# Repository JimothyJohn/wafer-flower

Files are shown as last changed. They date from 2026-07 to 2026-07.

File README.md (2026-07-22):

# [Wafer Flower](https://jimothyjohn.github.io/wafer-flower/)

It's the seeds of an idea.

Not a set of programming instructions, but a set of build instructions.

Dimensions clearly understood, relationships alive and interconnected, numbers converted to text to numbers to vectors to topology from your brain onto the 3D printer...it's not a wafer flower, it's not AI slop either, it's not even hard. It's it.

## Really though, what is it?

The current CAD is viewable live at [jimothyjohn.github.io/wafer-flower/viewer.html](https://jimothyjohn.github.io/wafer-flower/viewer.html) — the real exported STLs, with the cure jig opening and closing, the wafer placing, the ring connecting station by station, and the interference checks that gate every one of those configurations in CI.

It's an experiment in how to collaborate iwth AI in both the digital and physical world. Information is contextualized, digested understood, and converted into beautifully-printed reality. Also a ways in I was blown away by how well CAD could be generated, see [stl/](stl/). The entire workholding conceptually made sense and looked like it would actually work...

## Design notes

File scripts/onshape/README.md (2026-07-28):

# OnShape FeatureScript port — Halo beveloid drive

`wafer_halo_beveloid.fs` gives OnShape native, procedural generation of the
gear at the segment edge (straight or spiral), in the style of Anthony Lu's
**Gear Lab** FeatureScript. Paste it into a Feature Studio (New tab →
Feature Studio), commit, and the two features appear in the Part Studio
toolbar under the custom-features flyout.

## The two features

| Feature | What it builds | How to use it |
|---|---|---|
| **Halo Beveloid Band** | One segment's 40° external tooth band: 45° cone big-at-wall, flush root at the band OD, joints mid-space. | Build at origin (wall face on XY, sector centred on +X), then boolean-union onto the segment body. `Full ring` gives all N sectors for assembly checks. |
| **Halo Crossed Pinion** | The Rev B.5 drive pinion: 20T 45° cone (Ø9.9→Ø25.3 tips), apex toward the halo centre, hub + D-bore on the big end. | Mate its axis **radial** — vertical at 12 o'clock, motor above, shaft down — small end at the reported ring radius, axis ~13.6 mm in front of the ring's wall plane. Ratio 5.4:1 → ~2 rpm, PWM-dialed. |

Both features default to the shipped Rev B.3 numbers (N=9, Ri=255, bw=30,
module 5.6 nominal → 5.384 flush, face 9.5, PA 20°, straight teeth). Spiral
is one slider — the sections get the same twist the Python twist-extrude
applies.

## Why not Gear Lab directly?

Gear Lab is excellent for its domain, but its bevel gears are **spherical
involutes for intersecting shafts sized for true rolling** — and a
true-rolling 45°/45° pair only exists at 1:1. The halo pair runs 90° shafts
at 5.4:1 with both members on 45° cones, which no rolling-cone construction
allows; the flanks are conjugate because the Python model **generates**
them under the imposed motion, and the FS features rebuild those envelopes
analytically. The pinion can also be far smaller than the rolling size
(rho is free — that's what keeps the sculpture low-profile). Gear Lab also
has no ring-sector output, no flush-root module retune, and no joint-phase
convention.

Gear Lab is still the right tool if you just want to eyeball a 45° bevel
pair on intersecting axes, or generate a plain spur.

## Fidelity vs the Python model

`scripts/segment_stl.py` **generates** the ring as the swept envelope of
its cutter (conjugate by construction, mesh sweep gated at ≤0.05 mm³). The
FS features build **analytic involute sections and loft** — identical at
the mid-face, a few hundredths off toward the faces. At this drive's
~mN·m loads that is cosmetic; keep backlash ≥ 0.3 mm on printed parts (the
repo ships 0.3 — at the pinion's 0.8 mm section module, 0.6 would halve
the tooth). The Python gates remain the authority for anything that
prints — in particular the **gear_F ceiling** (face height must clear the
neighbour wafer's clearance plane; the gate computes 9.83 mm at the deep-bevel base (tmin=15)).

## Crib sheet at Rev B.5 (low-profile)

- 108T ring (12/segment), flush module **5.384** (5.6 nominal)
- Front radii: root 284.0, pitch 290.7, tip 296.1; wall = front × 1.0327
- Face 9.5 mm, cone 45°, straight (spiral 0°)
- 20T crossed pinion: pitch rho 8 (FREE — not the rolling value; conjugacy
  is by generation; 8 at 20T = the 0.8 mm section-module print floor),
  face 7, tips Ø9.9→Ø25.3, axis 13.6 mm off the wall plane
- Ratio 108/20 = **5.4:1** — ~2 rpm at the ring from an ~11 rpm shaft
  (22PG-2430BL 720:1, integrated driver, PWM-dialed; catalog-typical
  ~16 rpm no-load → ~3 rpm ceiling)
- Hub Ø16 × 6 mm on the big (motor) end, bore Ø4.2 with 0.5 D-flat
  (22PG 4 mm D-shaft — catalog-typical, measure the purchased unit)

`docs/onshape-variables.html` still carries the 46 copy-paste variable
expressions for the rest of the segment; these features replace only the
gear, which was the one part DXF import couldn't make parametric.

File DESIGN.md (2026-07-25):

# Design Guide

This is a high-level design guide that will aid with the creation of an optimal sectional mounting frame based on specific design criteria.

## Fabrication

This will be manufactured on a Bambu H2S printer.

## Concepts

### Symmetry

All components should be idnetical and designed in such a way that they easily assemble together without tools. There will be an assembly jig that attaches to each frame component, and the sculpture will be mounted by taking advantage of the same jig mounting features to attach it to the wall.

### Footprint

The frame should be as low profile as possible while still limiting interference from 300mm wafers neighbored, mounted, and tilted towards its adjacent components.

### Drivetrain

Each segment will incorporate a spiral bevel rack on the inner (outer is possible in the future) radius that will engage a pinion to rotate the entire frame at a constant velocity.

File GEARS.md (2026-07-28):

# GEARS.md — why these bevel gears work, and how to generate yours

This is the clinic. It explains why the Wafer Halo's gear train — a 108-tooth
45° bevel rack on the sculpture's OD, driven at 5.4:1 by a 20-tooth conical
pinion on a vertical shaft — meshes correctly *as generated*, why classical
bevel-gear theory said it couldn't exist, and exactly which constraints are
load-bearing versus free, so the same method can be re-targeted
algorithmically (different ring size, ratio, motor, cone angle) without
re-deriving anything by hand. Every claim cites the code that enforces it;
all excerpts are from `scripts/segment_stl.py` unless noted.

The one-sentence version: **don't specify tooth flanks — carve them, by
sweeping the actual mating part through the exact relative motion, and let
boolean gates prove the result.**

---

## 1. The problem that theory can't solve

The drive wants four things simultaneously:

1. A **45° straight bevel rack** on the ring's outside diameter — the mixer
   look, working face toward the viewer (aesthetic, non-negotiable).
2. A **~2 rpm target** at the sculpture, minimalist over exact. The 5.4:1
   ratio (20T pinion) puts any small gearmotor in range: the 22PG-2430BL
   720:1 (integrated driver, catalog-typical ~16 rpm no-load) lands ~3 rpm
   and PWMs down to taste; the earlier Pololu #1596 at 5 V (10.83 rpm
   no-load) would give 2.006 rpm on the same teeth.
3. The pinion shaft **pointing straight down** (radial at 12 o'clock), motor
   directly above it.
4. Packaging: silicon wafers own *all* space in front of the ring (their
   undersides sweep within millimetres of the tooth band), and drywall owns
   the space behind.

Classical bevel gearing cannot deliver this. Two true-rolling bevel gears
must share a pitch-cone **apex** on the line where their shafts intersect,
and the cone angles are then *dictated* by the ratio:
`tan δ₂ = sin Σ / (ratio + cos Σ)`. Consequences, all measured in this repo
before being abandoned:

- A **45°/45° pair only rolls at 1:1**. At 5.4:1 with 90° shafts the ring
  cone must be ~79.5° (nearly a flat face gear) and the pinion ~10.5° (nearly
  a spur) — no mixer look.
- Keeping the ring at 45° and solving for true rolling puts the shared apex
  **~300 mm in front of the wall** on the halo axis; the pinion and motor
  would hang in the wafer field.
- The interim parallel-axis beveloid solved packaging but put the shaft
  along the wall normal — not the drive Nick specified.
- A rolling-sized radial-axis pinion (pitch = ring pitch ÷ ratio = 26.9 mm)
  ballooned to Ø100 at the big end and forced a 108 mm-tall part before the
  size assumption was questioned (§4).

## 2. The move: generation, not specification

The escape is the same one machine tools use. A hobbed or shaped gear is
never *drawn* — the cutter and blank are driven through the meshing motion
and the flanks emerge as the envelope of material that survives. Conjugacy
is then true **by construction**: the running pinion cannot interfere with
flanks its own shape cut while executing the exact motion it will run.

Here that principle is executed volumetrically with CSG (`manifold3d`): the
cutter is a solid model of the pinion, placed at ~500 successive poses of
the relative motion, unioned, and subtracted from the ring blank. The core
of `gear_teeth_bevel45()`:

```python
# segment_stl.py, gear_teeth_bevel45() — the generation sweep.
# One pose per step: the pinion spun ratio*d about its own axis, placed on
# the radial axis, then the whole pose rotated -d so the ring stays still.
cutter_pin, _ = bevel_pinion(cf, backlash=0.0, over=0.5)
n = steps or (48 * int(round(cf.gear_m)) + 1)
span = span_pitches * (2.0 * math.pi / cf.teeth)      # ±2 ring pitches
cut = union_all([(bevel_pinion_at(cf, cutter_pin,
                                  -span / 2.0 + span * i / (n - 1), dr=-0.3)
                  .rotate([0, 0, -math.degrees(-span / 2.0
                                               + span * i / (n - 1))]))
                 for i in range(n)])
gen = blank - cut
```

and the pose function that encodes the crossed-axis kinematics:

```python
# segment_stl.py, bevel_pinion_at() — the imposed motion.
def bevel_pinion_at(cf, pin, d, dr=0.0):
    bg = bevel_geom(cf)
    return (pin.rotate([0.0, 0.0, math.degrees(d * bg['ratio'])])
               .rotate([0.0, 90.0, 0.0])
               .translate([bg['x0'], 0.0, bg['zax'] + dr]))
```

Read it kinematically: while the ring turns `d`, the pinion turns
`ratio · d` about its own (radial) axis. `rotate([0,90,0])` maps the
pinion's local +z (its axis) onto the global radial direction, which also
lands its phase-0 tooth pointing down into the ring. The `.rotate(-d)` in
the sweep transfers the ring's share of the motion onto the cutter, so the
blank can stay fixed. That pair of lines *is* the gear theory in this repo.
The spin sign was derived once by matching surface velocities at the
contact and is *verified*, not trusted — a wrong sign reads as hundreds of
mm³ in the mesh gate (§6).

Because the flanks are an envelope of an imposed motion rather than rolling
involutes, this pair runs with sliding contact, like a cam or a worm. At
this drive's loads (~3 mN·m needed against a 0.54 N·m stall through the
gearbox) sliding is irrelevant; the printed PLA pinion doubles as the
mechanical fuse.

## 3. The two constraints that are actually load-bearing

Everything about this drive is negotiable except two integers.

**Ring tooth count must divide by N.** The ring is assembled from N=9
identical printed segments; if the tooth pattern doesn't tile the 40° joint
exactly, the pitch breaks at every seam. So `teeth = tps × N`, and the
pattern is phased so **every joint lands mid-space** (a space at azimuth 0,
copies at `k·pitch` — see §5d).

**Ratio = ring teeth ÷ pinion teeth, exactly.** Tooth-passing frequency
must match at the mesh, so `108 / pin_T = ratio`. Wanting ~2 rpm forces
`pin_T = 20` (5.4:1). This is the *only* thing the RPM goal fixes:

```python
# segment_stl.py PARAMS
pin_T    = 20,      # pinion tooth count. 108T ring / 20T = 5.4:1 —
                    # the Pololu #1596 at 5 V (10.83 no-load rpm) gives
                    # 2.01 rpm at the ring (2026-07-27, Nick: ~2 rpm is
                    # fine, minimalist profile beats exact-1; pin_T 10
                    # was the 1.00 rpm build). NOTE finer RACK teeth
                    # would RAISE the profile: more ring teeth needs
                    # more pinion teeth per ratio, and the pinion's
                    # printability floor is its section module
                    # (2*pin_rho/pin_T >= ~0.8).
```

One subtlety worth internalizing: pinion tooth count and pinion *size* are
coupled through printability, not kinematics. A 20T pinion at rho 8 has a
0.8 mm section module — the FDM floor — so doubling the tooth count again
(1 rpm-class ratios with finer rack teeth) would force a *bigger* pinion
and a *taller* part. Coarse rack + few-but-chunky pinion teeth is the
low-profile direction.

Note what is *not* on this list: the pinion's size, and even its cone
angle. That's the subject of the next section, and it's the difference
between the Ø100 monster and the Ø25 pinion that shipped.

## 4. The freedom theorem: pinion size is a style knob

Textbook reflex says the pinion's pitch radius must be
`ring_pitch / ratio` (rolling contact at the pitch point). The first
crossed-axis build obeyed that reflex — rho 26.9 mm, tips Ø100, the motor
36 mm off the wall, the whole part 108 mm tall — and got the correct
review: *"way out of scale… it should be right up on its nuts."*

The reflex is wrong **because generation owns conjugacy**. The sweep makes
the ring conjugate to whatever cutter executes the motion; rolling is a
contact-quality optimization, not a meshing requirement. Only the tooth
count is forced. So the pinion's pitch radius and engaged face are free
parameters, sized for packaging:

```python
# segment_stl.py PARAMS
pin_rho  = 8.0,     # pinion mid-face pitch radius. FREE, not the
                    # rolling value (conjugacy is by generation; only
                    # the COUNT is forced). 8 with pin_T 20 = 0.8 mm
                    # section module — the printable floor, and the
                    # low-profile knob: the standoff is ~2.25*rho +
                    # gear_F/2 + face/2 dominated.
pin_face = 7.0,     # pinion face length along its axis: engages the
                    # OUTER pin_face mm of the tooth radial envelope.
```

With rho = 8 the pinion is a Ø9.9→Ø25.3 cone, its axis 13.6 mm off the
wall face, and the derived wafer standoff collapses to +17.6 mm (§7) —
the rolling-size first cut was +78, the rho-12 rev +31. The floor is the
0.8 mm section module (`2·pin_rho/pin_T`): below that FDM teeth stop
resolving. The cost of abandoning rolling is extra sliding — already
accepted at these mN·m loads.

## 5. The recipe

### a. Size the ring teeth: flush module by retune

Tooth count is quantized in steps of N, so the pitch radius can't be tuned
by count. Instead the *module* is retuned so the root circle lands on the
band's outer wall — teeth rise straight off the part, no bare web:

```python
# segment_stl.py, Cfg — FLUSH MODULE
target = self.Ro + 1.25 * self.gear_m + 2.0
self.tps = max(6, int(math.ceil(2 * target / self.gear_m / self.N)))
self.teeth   = self.tps * self.N
if self.g_bev:
    self.gear_m = (self.Ro - 1.0) / (self.teeth / 2.0 - 1.25)
```

At the shipped numbers: nominal module 5.6 → 12 teeth/segment → 108 teeth →
effective module 5.384, root at r284 against the band OD at 285.

### b. The ring blank owns the look

The visible 45° cone is *not* produced by the cutter — it's the blank: an
annulus intersected with a cone, big end at the wall (radius falls 1 mm per
mm of z toward the viewer):

```python
# segment_stl.py, gear_teeth_bevel45() — the blank
big = cf.g_tip * cf.g_kbig + 1.0
blank = prism(arc(big, -cf.half, cf.half, 200) +
              arc(cf.g_web_i, cf.half, -cf.half, 200), 0.0, F)
tipcone = (Manifold.cylinder(F + 0.2, cf.g_tip * cf.g_kbig + 0.1,
                             cf.g_tip + 0.1, 512)
           .translate([0.0, 0.0, -0.1]))
blank = blank ^ tipcone
```

This separation matters for generality: change the blank and the gear's
silhouette changes; the cutter sweep only decides where the working flanks
are. The face height `gear_F` has a *live-computed* ceiling — the band must
clear the neighbouring wafer's clearance plane, measured by
`gear_F_ceiling()` and enforced by a gate in `main()` that fails the build
if the mandatory clearance cut removes any tooth material.

### c. Build the cutter: a cone of scaled involutes

The cutter (and the printed runner) is the pinion: standard external
involute sections, scaled linearly along the axis so the envelope is a 45°
cone. Linear scaling with `scale_top` gives exactly 1 mm of radius per mm
of length:

```python
# segment_stl.py, bevel_pinion() — sections scaled (station − apex)/rp0
s_lo = (bg['x0'] - over - bg['apex']) / rp0
s_hi = (bg['x1'] + over - bg['apex']) / rp0
p = Manifold.extrude(CrossSection([pts]), bg['face'] + 2 * over,
                     n_divisions=16, twist_degrees=tw,
                     scale_top=(s_hi / s_lo,) * 2)
```

Two details are traps, both encoded: `over=0.5` extends the cutter past
both faces (a cutter ending exactly on a face leaves sliver faces that read
as OPEN after the float32 STL weld), and `twist_degrees` is where a spiral
would go — set `gear_sp`, and the *generated ring inherits the conjugate
spiral automatically*, because the sweep doesn't care what the cutter looks
like.

### d. Sweep, extract, pattern, clip

The sweep spans ±2 ring pitches (`span_pitches=4`) — enough for the cutter
to fully enter and leave a space, which is also what proves tooth handoff.
Then one pitch is extracted and patterned, because the motion is periodic:

```python
# segment_stl.py, gear_teeth_bevel45() — pattern and clip
one = gen ^ wedge                       # one-pitch sample, cut at angle 0
teeth = union_all([one.rotate([0.0, 0.0, -math.degrees(cf.half) + k * pitch])
                   for k in range(cf.tps + 1)])
eps = 1e-5
sector = prism([(0.0, 0.0)] + arc(big + 100.0, -cf.half + eps,
                                  cf.half - eps, 64), -1.0, F + 2.0)
teeth = teeth ^ sector
```

Three phase/pattern rules, each learned the hard way (measured values in
CLAUDE.md): the cutter cuts a **space at angle 0**, so copies tile at
`k·pitch` from the joint (a half-pitch offset reads as ~156 mm³ of joint
interference); **tps+1 copies** are generated then clipped (an unclipped
end wedge lands 232 mm³ inside the neighbour segment); and the sector clip
backs off **1e-5 rad** from the exact joint plane (numerically coincident
faces on assembled neighbours read as phantom interference).

Tip relief is **radial** — the cutter runs with `dr = -0.3`, i.e. its whole
axis 0.3 mm closer to the ring than the runner will sit, so slot floors are
uniformly deeper than running tips. The obvious alternative (shifting the
cutter along z) was shipped once and left a visible uncut 0.3 mm shelf ring
at the wall-face edge of every tooth.

### e. The cosmetic pass: look and function, decoupled

The small pinion only needs the outer 10 mm of the tooth envelope, but the
*visible* pattern should span the whole 45° face. So a second sweep runs a
full-face parallel-axis beveloid cutter over the blank, purely for
appearance. This is safe by a monotonicity argument worth internalizing:
**extra material removal can only add clearance** — it cannot create
interference — so the mesh gate is untouched. Both patterns tile at
`k·pitch`, so they align tooth-for-tooth:

```python
# segment_stl.py, gear_teeth_bevel45() — cosmetic pass (excerpt)
# ... the small crossed pinion only carves the outer pin_face of the
# envelope; the visible deep-bevel tooth pattern is restored by ALSO
# sweeping the old parallel-axis 12T beveloid cutter over the full face.
cut = cut + union_all([
    (cos_pin.rotate([0.0, 0.0, -math.degrees(d * cf.teeth / cf.tps)])
            .translate([C - 0.3, 0.0, 0.0])
            .rotate([0, 0, -math.degrees(d)]))
    for d in (-span / 2.0 + span * i / (nc - 1) for i in range(nc))])
```

### f. Cutter vs runner: backlash by thinning

The generating cutter runs at zero backlash; the printed runner is the same
solid with teeth thinned by `gear_bl = 0.6` mm (`pinion_profile`'s
`psi_p` term). Running clearance therefore exists **by construction**:
flank clearance from the thinning, tip clearance from the radial relief.
0.6 mm is the printed-PLA tune; it is a parameter, not a constant.

## 6. Why meshing is guaranteed — the gates

Generation makes interference impossible *up to discretization* (the sweep
is a union of poses, so the true envelope is scalloped at the step
spacing). The residual is measured, not assumed:

```python
# segment_stl.py, check_mesh() — roll the RUNNER against the generated
# teeth through one full ring pitch and measure boolean overlap
for i in range(steps):
    d = (2 * math.pi / cf.teeth) * i / steps
    r2 = ring.rotate([0, 0, math.degrees(d)])
    p2 = bevel_pinion_at(cf, pin, d)
    worst = max(worst, (r2 ^ p2).volume())
```

CI fails the build if `worst > 0.05 mm³`; the shipped geometry measures
**0.00000 mm³**. The same number is the arbiter for the motion's spin sign
and phase — a wrong sign or a half-pitch phase error reads as hundreds of
mm³, so the convention can never silently rot.

The rest of the gate suite closes the environment: the neighbour-wafer
clearance cut must remove zero tooth material (its ceiling on `gear_F` is
computed live from the wafer geometry, not frozen in a comment); assembled
neighbour segments must measure exactly 0 interference; every body must be
watertight with the expected genus, with sub-0.01 mm³ specks filtered at
the source because a disconnected crumb cancels a handle in the Euler count
and masquerades as correct topology. Downstream, `bracket_stl.py` checks
the *running context*: the pinion against the full ring + wafer field at
nominal, the wall plane including the pinion's swing, and the wheel datum
that preloads the mesh.

## 7. Packaging closes the loop

Two derived quantities tie the gear to the sculpture, both computed in
`Cfg`, neither hand-maintained:

- **`stand`** — the wafers must clear the pinion's front bulge, so the part
  grows exactly as much as the drive needs:
  `pin_bulge = pin_zax + (pin_x1 − pin_apex)·(1 + 2/pin_T)`, and
  `stand = pin_bulge + 3 − gap₀`. At rho 8 that's +17.6 mm (+31 at rho 12,
  +78 at the rolling-sized pinion — shrinking the pinion shrinks the
  sculpture, until the 0.8 mm section-module print floor stops it).
- **wall gap** — the pinion's lower teeth swing `(x1−apex)·(1+2/pin_T) −
  zax` past the ring's wall face (at shipped numbers that's −0.9 mm: the
  small pinion never crosses the wall plane); the mount holds the ring
  6 mm off the drywall and the wall-plane check proves it either way.

The mount side completes the mesh mechanics: the two bore idlers hang the
ring **at the meshing meridian**, so the pinion presses against a hard
radial datum, and the motor shell rides ±8 mm slots to set engagement depth
(preload) before clamping.

## 8. Re-targeting checklist (the algorithm, as an algorithm)

To generate a different bevel drive with this machinery:

1. Pick ring size (`Ri`, `bw`) and nominal module for tooth chunkiness;
   the flush retune (§5a) makes the count/size self-consistent.
2. Pick the ratio from your speed goal; `pin_T = teeth / ratio` must land
   on an integer — that's the only place the RPM constrains the geometry.
3. Pick `pin_rho` and `pin_face` for packaging (motor location, bulge,
   behind-face swing). These are free (§4).
4. Pick the blank's cone (`gear_F`, big end direction) for looks, under
   the live environmental ceiling.
5. Optional spiral: one parameter (`gear_sp`); the ring inherits it.
6. Run the generator. The sweep produces the conjugate flanks; the gates
   (mesh sweep, clearance cut, pair fit, watertightness, context checks)
   either prove the result or point at exactly which assumption broke.

Nothing in the list involves drawing a tooth.

---

*Related: `scripts/onshape/wafer_halo_beveloid.fs` reproduces the ring
band and pinion analytically for OnShape CAD work (parity-tested spec
math); the generated Python parts remain the authority for anything that
prints. History and the full trap ledger live in `CLAUDE.md`.*

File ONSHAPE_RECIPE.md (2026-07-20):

# Build v3 in OnShape from the DXFs — 7 features

Import both DXFs as sketches on the Top plane (they share the same global
coordinate system; segment is centered on +X).

## The one construction that matters: the LAND PLANE
1. Sketch a line on Top along the TILT_AXIS layer (through wafer center
   (350,0), pointing radially).
2. Plane > Line Angle: through that line, 20 deg from Top. This is the
   WAFER MID-PLANE.
3. Offset plane: -0.887 mm below it (wafer half-thickness 0.3875 + 0.5
   bond line). This is the LAND PLANE.

## Segment (one part, pattern is implicit — print 9)
1. Extrude SECTOR profile DOWN 8 mm (base).
2. Extrude LAND_FOOTPRINT profile UP 40 mm, merge with base.
3. Split/Remove everything above the LAND PLANE (Boolean with a large
   extruded region, or Surface > Plane + Split part, delete upper body).
   The surviving ramped top face is the bonding land.
4. Dovetails: on the +20 deg radial end face sketch DT_MALE, extrude 8 out;
   on the -20 deg face sketch DT_FEMALE, extrude cut through.
5. Nubs: sketch 3x d4 circles ON THE LAND PLANE at (220,0), (235,±32.89)
   [plan coords — use the NUBS_D4 layer as reference], extrude UP 0.5 mm.
6. Keyhole: cut 3 deep into the bottom face from the KEYHOLE layer.

## Jig
1. Extrude RAIL_IN and RAIL_OUT down/up per notes (rails 13 tall total,
   dropping 8 below Top to straddle the segment base).
2. Registration dovetail: reuse DT_MALE minus ~0.05 on the -20 deg end.
3. Fences: extrude FENCE_* profiles from the LAND PLANE up ~5.5 mm
   (use Up to Next/offset from the tilted plane, not from Top — the fence
   top must parallel the wafer, not the bench).
4. Bridge: extrude BRIDGE_FOOTPRINT as a bar spanning the rails ~30 above
   Top; cut the M5 hole NORMAL TO THE WAFER MID-PLANE at plan (228, 0);
   hex nut pocket 8.1 AF x 4.2 on top.

## Numbers you'll want while modeling
- Wafer: d300 x 0.775. Halo: N9, pitch R350, tilt 20 about radial axis.
- Sector: 40 deg, Ri 175 / Ro 245, base 8. Dovetail 12/16 x 8, clr 0.25.
- Land margin inside wafer edge: 3. Bond line: 0.5 (nubs d4 x 0.5).
- Fence inner face at R150.3 from wafer center; walls 5 thick.
- Bond adhesive: MS-polymer (SikaFlex 252 / Loctite PL), not rigid epoxy.

## Sanity checks after modeling
- Section through the wafer mid-plane: wafer back should sit 0.5 above the
  land everywhere, kissing the three nubs.
- Assembly with 9 instances @ 40 deg: neighbor wafer clears this segment's
  land everywhere (it does at 20 deg tilt by ~50 mm; verify if you change
  tilt, R_pitch, or ring widths).
- Land must stay inside the wafer outline in front view (3 mm margin).

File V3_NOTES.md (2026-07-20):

# Halo v3 — adhesive mount, zero frame hardware

## What's on the frame (per segment, x9)
Dovetails, three 0.5 mm bond-line nubs, an underside keyhole. Nothing else.
The bonding land is generated by cutting the segment blank with the
wafer-back plane, so it is coplanar with the wafer underside by construction
and covers every point where the wafer footprint overlaps the frame
(~110 x 40 mm lens through the segment middle at default params).
Want more land? Widen body_ri/body_ro — do NOT expect land at the segment
ends; the wafer has curved away there.

## Bonding procedure (bench, one segment at a time)
1. Print jig once. Fit-check jig on a bare segment: dovetail seats, rails
   straddle the base with no rock.
2. Dry-run: wafer onto the land, slide until edge rests on the downhill
   fence, finger-press toward the 180° fence pad until it touches both.
   That's centered. Practice this before adhesive.
3. Mask nothing; apply MS-polymer (SikaFlex 252 / Loctite PL) in a
   serpentine bead over the land, staying ~5 mm inside its edge.
4. Place wafer, center against fences as rehearsed, install clamp knob,
   turn until the pad JUST contacts, then 1/4 turn. The nubs stop it —
   you are setting bond line, not applying force.
5. Cure per datasheet (MS polymers: handle 24 h, full 72 h). Remove jig,
   next segment.
6. After all nine: dovetail the ring together, hang on 3 keyholes.

## Adhesive
MS-polymer or E6000, not rigid epoxy: PLA/PETG vs silicon CTE mismatch over
a 110 mm bond puts thermal shear into the wafer. If you insist on epoxy,
use a flexibilized one (3M DP125) and keep the 0.5 mm bond line.

## Known v1 risks — check on first render/print
1. UNRENDERED (no OpenSCAD in my environment). projection() of the tilted
   cylinder is the one construct most likely to be slow or need a render
   (F6) instead of preview; if it drags, replace wafer_footprint_prism()
   with a linear_extrude of an approximated ellipse (semi-axes 150 radial,
   150*cos(tilt) tangential, centered at R_pitch).
2. Jig fence struts and bridge are placed by hand-calculated offsets —
   expect to nudge them after first F5. Printables (segment, jig) before
   scene modes.
3. The downhill fence assumes bonding with the segment flat on the bench
   (wafer plane tilted 20 deg, low side = local -Y/270 deg). If you bond in
   any other orientation, move the fence to whatever side is downhill.
4. Land surface is a plane cut across layer lines — print segments land-up
   with fine layers, or hit the land with one pass of filler/sand for full
   adhesive contact. Nubs survive light sanding; don't flatten them.

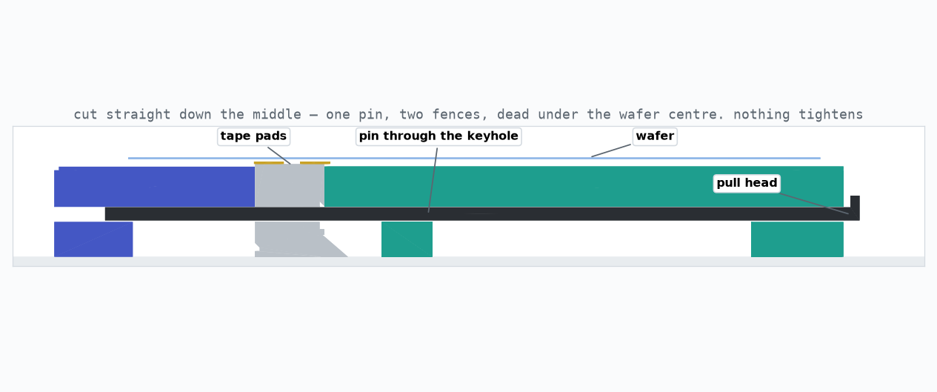
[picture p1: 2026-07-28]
docs/media/sec_drivetrain.png

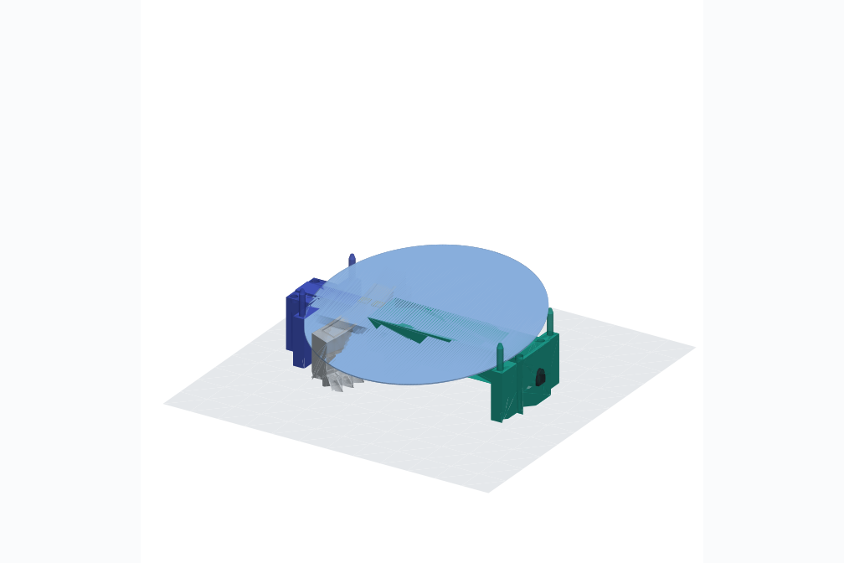
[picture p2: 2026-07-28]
docs/media/hero.png

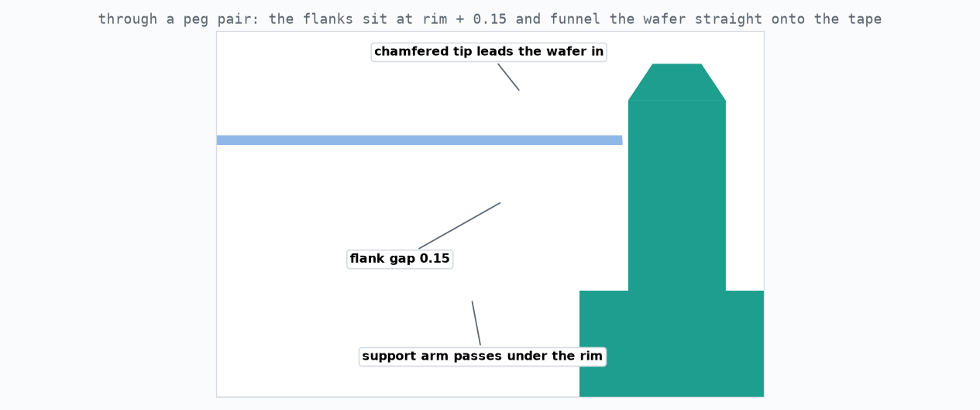
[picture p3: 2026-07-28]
docs/media/sec_capture.png

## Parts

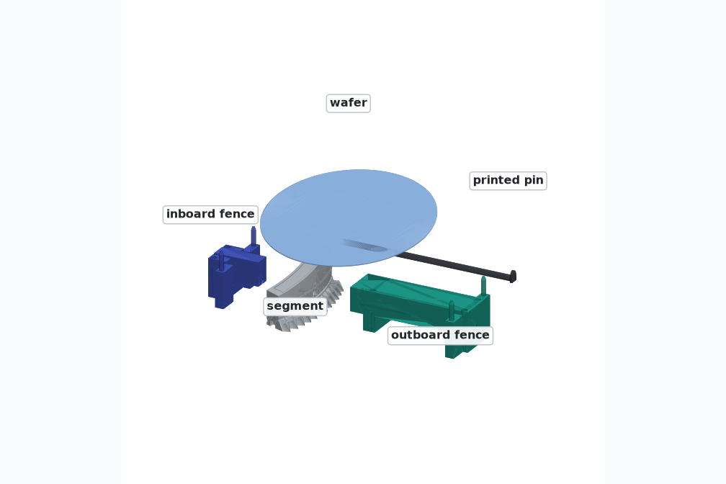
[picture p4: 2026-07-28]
docs/media/parts.png

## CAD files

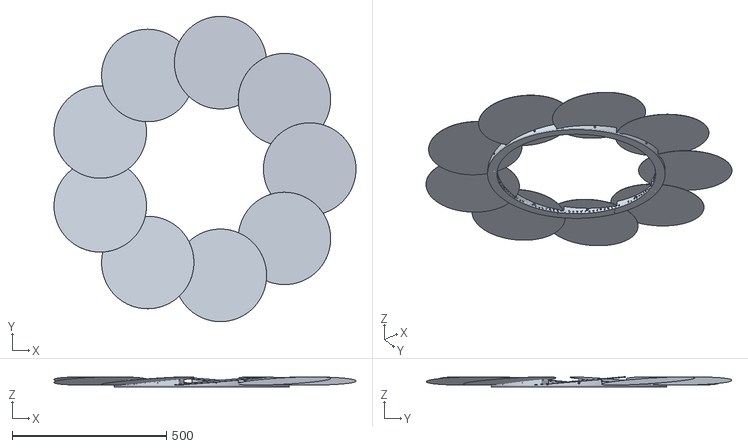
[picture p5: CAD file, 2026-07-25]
stl/halo_assembly.stl
978.8 x 989.3 x 33.5

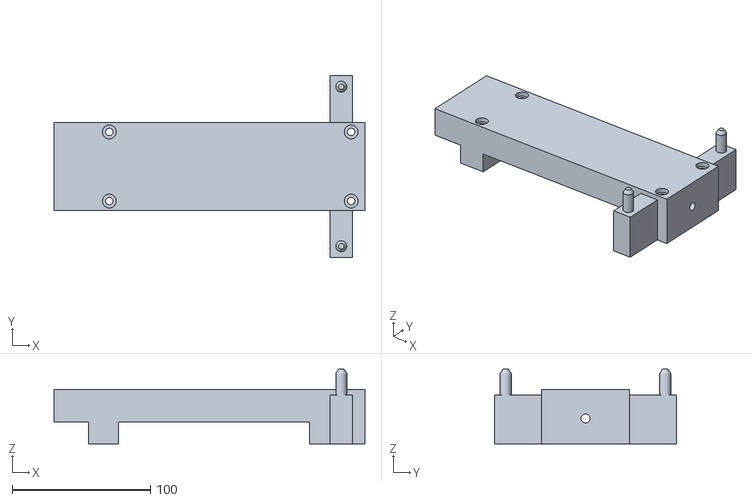
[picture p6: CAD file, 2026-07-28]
docs/models/jig_outboard.stl
225.0 x 131.4 x 54.0

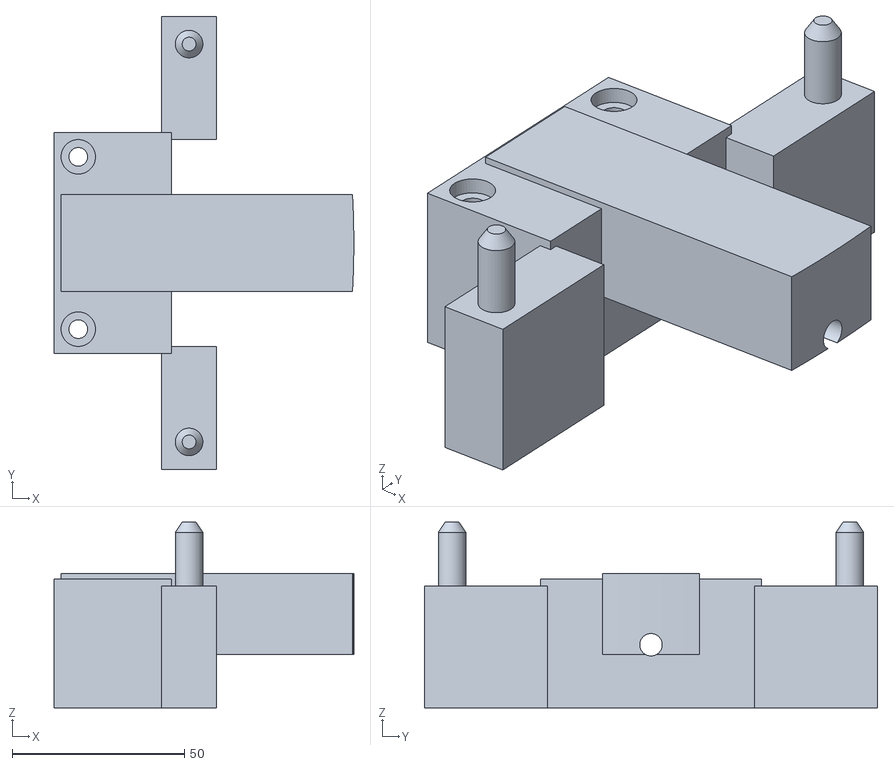
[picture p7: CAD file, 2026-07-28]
stl/cure_jig_inboard.stl
86.9 x 131.4 x 54.0

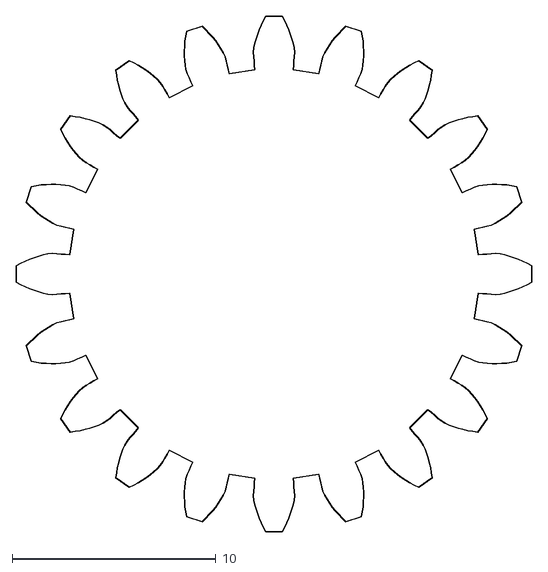
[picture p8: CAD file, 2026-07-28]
stl/dxf/05_bevel_cutter.dxf
25.3 x 25.3

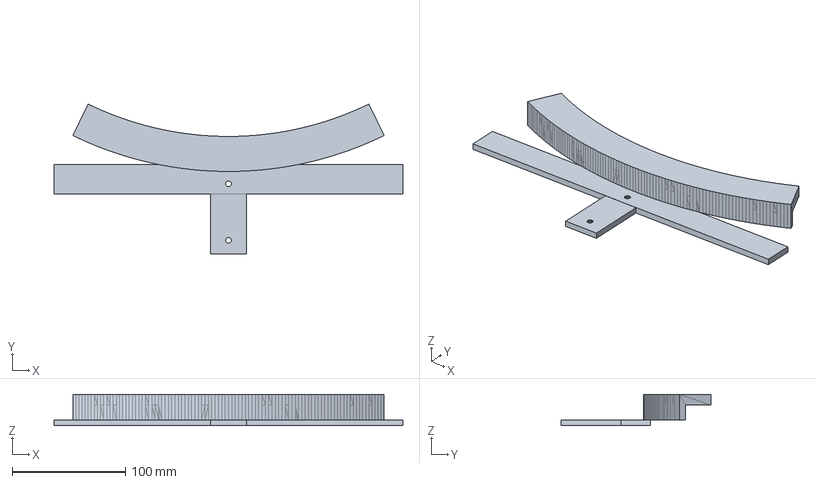
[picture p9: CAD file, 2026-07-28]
stl/step/bracket_static.stp
308.6 x 132.6 x 27.8 mm

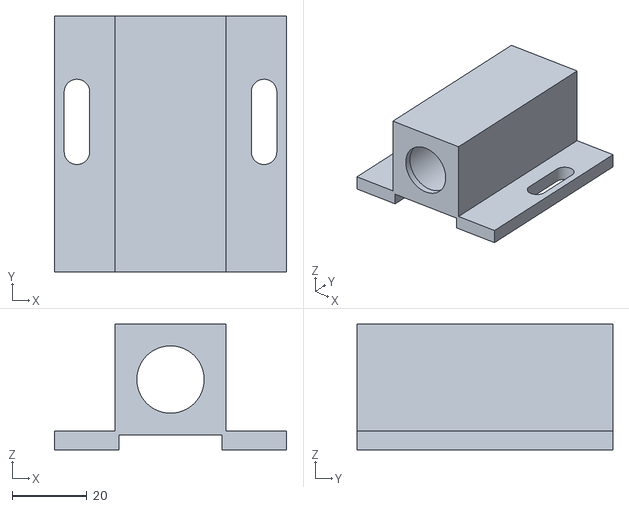
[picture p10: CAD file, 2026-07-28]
docs/models/bracket_shell.stl
62.0 x 68.4 x 33.6

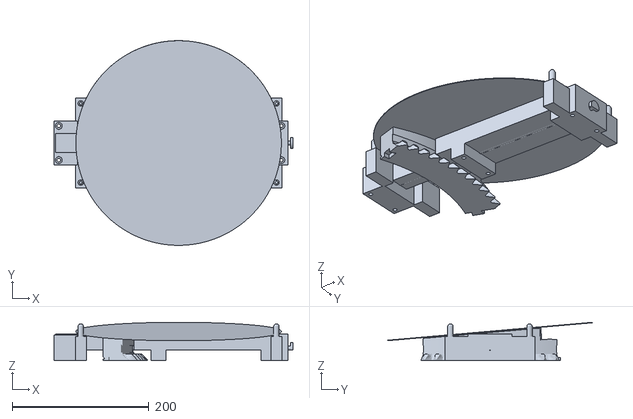
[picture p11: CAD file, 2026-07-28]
stl/cure_jig_fitcheck.stl
349.0 x 298.9 x 56.1

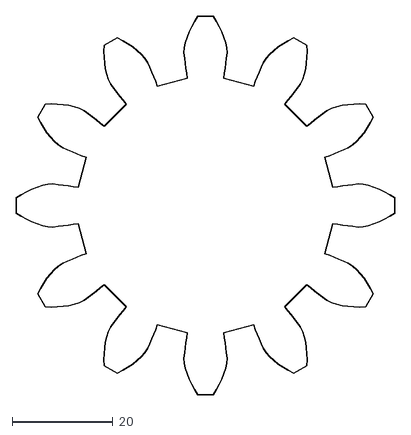
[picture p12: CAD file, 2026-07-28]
stl/dxf/06_pinion.dxf
75.3 x 75.3

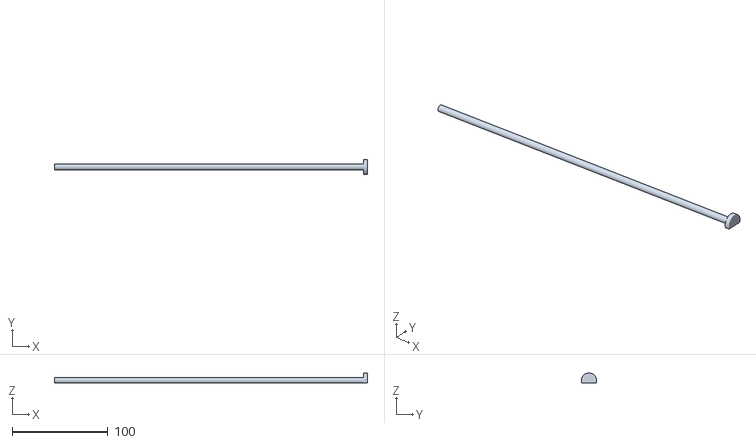
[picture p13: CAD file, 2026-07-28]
docs/models/rod.stl
327.0 x 16.0 x 10.6

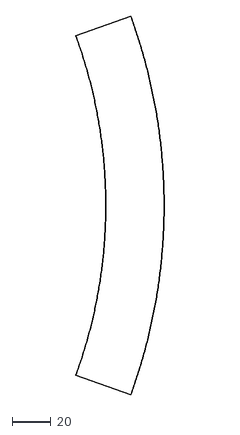
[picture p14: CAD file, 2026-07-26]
stl/dxf/01_band.dxf
45.4 x 194.9

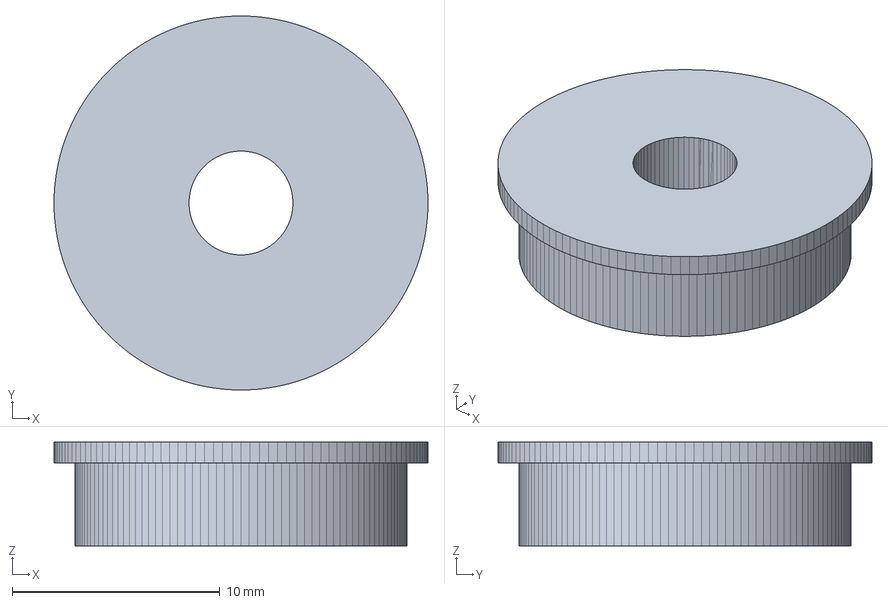
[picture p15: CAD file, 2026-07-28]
stl/step/bracket_wheel.stp
18.0 x 18.0 x 5.00 mm

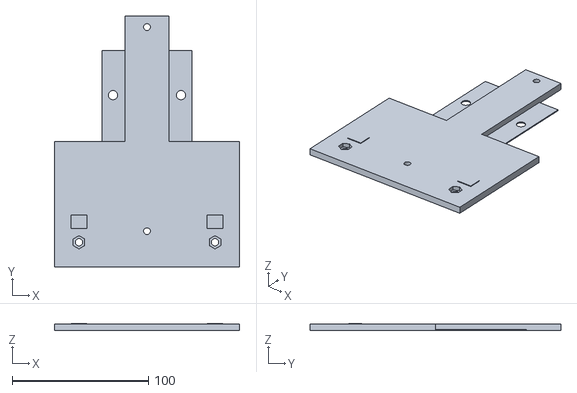
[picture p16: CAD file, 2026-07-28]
docs/models/bracket_top.stl
136.0 x 184.2 x 5.50

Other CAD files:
stl/step/bracket_shell.stp
stl/cure_jig_outboard.stl
stl/bracket_bottom_static.stl
stl/step/bracket_top.stp
docs/models/wheel_r.stl
docs/models/bracket_bottom.stl
docs/models/bracket_plate.stl
docs/models/bracket_static.stl
docs/models/drive_pinion.stl
docs/models/jig_inboard.stl
docs/models/my_frame_segment.stl
docs/models/segment.stl
docs/models/wafer.stl
docs/models/wheel_l.stl
stl/bracket_bottom.stl
stl/bracket_fitcheck.stl
stl/bracket_plate.stl
stl/bracket_shell.stl
stl/bracket_top.stl
stl/cure_jig_pin.stl
stl/drive_clamp.stl
stl/drive_fitcheck.stl
stl/drive_pinion.stl
stl/drive_plate.stl
stl/dxf/02b_tail.dxf
stl/dxf/03_socket.dxf
stl/dxf/04_pocket.dxf
stl/halo_frame.stl
stl/m5_nut.stl
stl/m5_screw.stl
stl/m6_nut.stl
stl/m6_screw.stl
stl/pinion.stl
stl/segment.stl
stl/segment_pair.stl
stl/step/bracket_bottom.stp
stl/step/bracket_plate.stp
stl/step/pinion.stp
stl/step/segment.stp
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

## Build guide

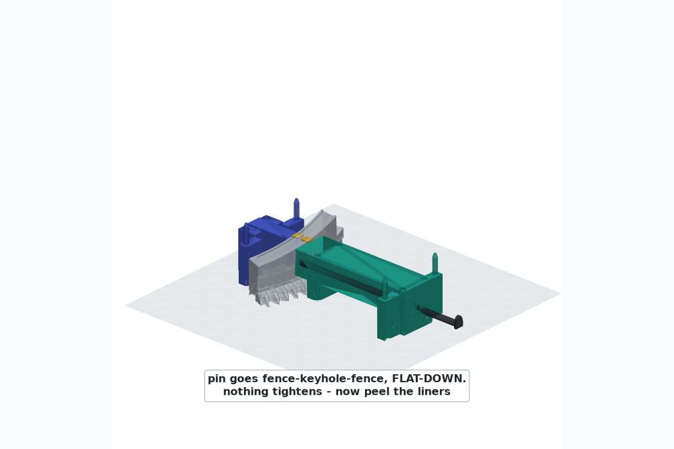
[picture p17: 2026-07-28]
docs/media/step5_pin.png

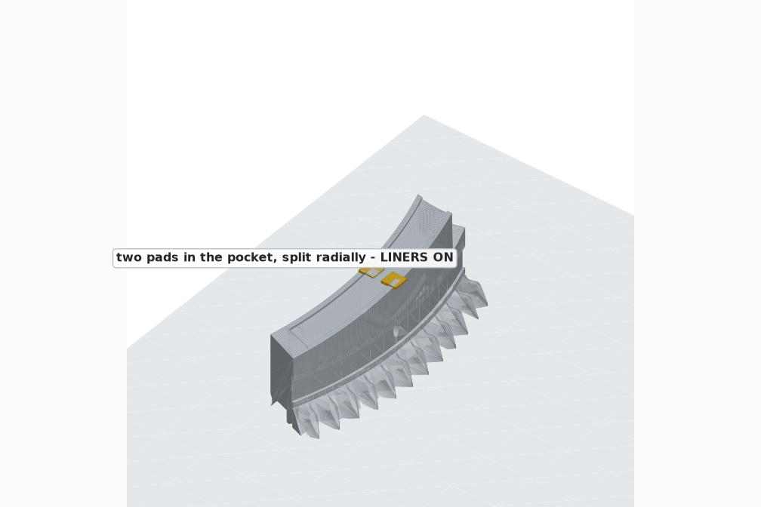
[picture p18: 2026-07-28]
docs/media/step2_tape.png

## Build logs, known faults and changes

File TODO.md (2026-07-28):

# TODO

## Open questions for Nick

(my_frame_segment.stl orientation answered 2026-07-21: same frame as
segment.stl; the viewer overlay expects that and warns until the re-export
lands)

- 2026-07-22 gearmotor: the drive plate's N20-worm envelope (46×12.6×10.2,
  Ø3 D-shaft, shaft 9 mm from the nose end) is catalog-typical, not measured.
  Which unit are you buying? Re-run scripts/gearmotor_stl.py with measured
  dims before printing drive_plate.stl.
- 2026-07-22 bracket interface: the plate hangs on TWO #10-24 pan heads,
  56 mm apart (y=±28), heads ~4 mm proud, in the plane 16.5 mm behind the
  frame's flat bottom (z=−36.5 scene). OK to freeze this as the bracket
  contract, or do you want a different fastener/spacing?
- 2026-07-22 viewer: add the drive module (plate/clamp/motor/pinion) to
  viewer_export.py + docs/viewer.html as a preset? Left out to keep the PR
  additive; the fitcheck STL covers it meanwhile.
(2026-07-26 drive-axis fork answered same day: crossed radial shaft
shipped as Rev B.5 — generation owns conjugacy, the small pinion clears
the wafer field from the front.)

- 2026-07-27 22PG-2430BL 720:1 envelope: bracket_stl.py carries
  CATALOG-TYPICAL dims (body Ø24, nose Ø22×20, length 65, Ø4 D-shaft —
  the RobotShop datasheet PDF is CDN-blocked from here; speed ~16 rpm
  no-load is interpolated from the 19:1/630 rpm and 1370:1/8 rpm
  siblings). Measure the purchased unit (body Ø + length, nose Ø +
  length, shaft Ø + flat, mount holes) and re-run bracket_stl.py before
  printing the shell. Also: it's a 24 V-class motor with an integrated
  driver — what's the supply plan (24 V brick + PWM pot, or a
  microcontroller)? USB 5 V won't run it.

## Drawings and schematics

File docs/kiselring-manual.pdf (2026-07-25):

×1

# KISELRING

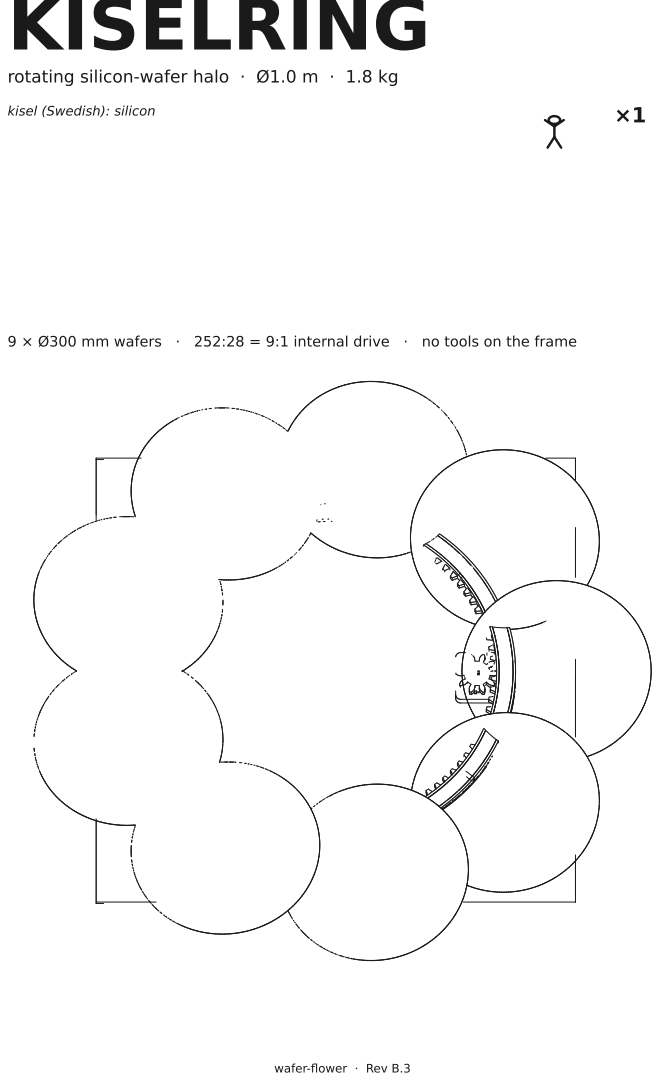
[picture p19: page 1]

rotating silicon-wafer halo · Ø1.0 m · 1.8 kg
kisel (Swedish): silicon

9 × Ø300 mm wafers · 252:28 = 9:1 internal drive · no tools on the frame

wafer-flower · Rev B.3

!

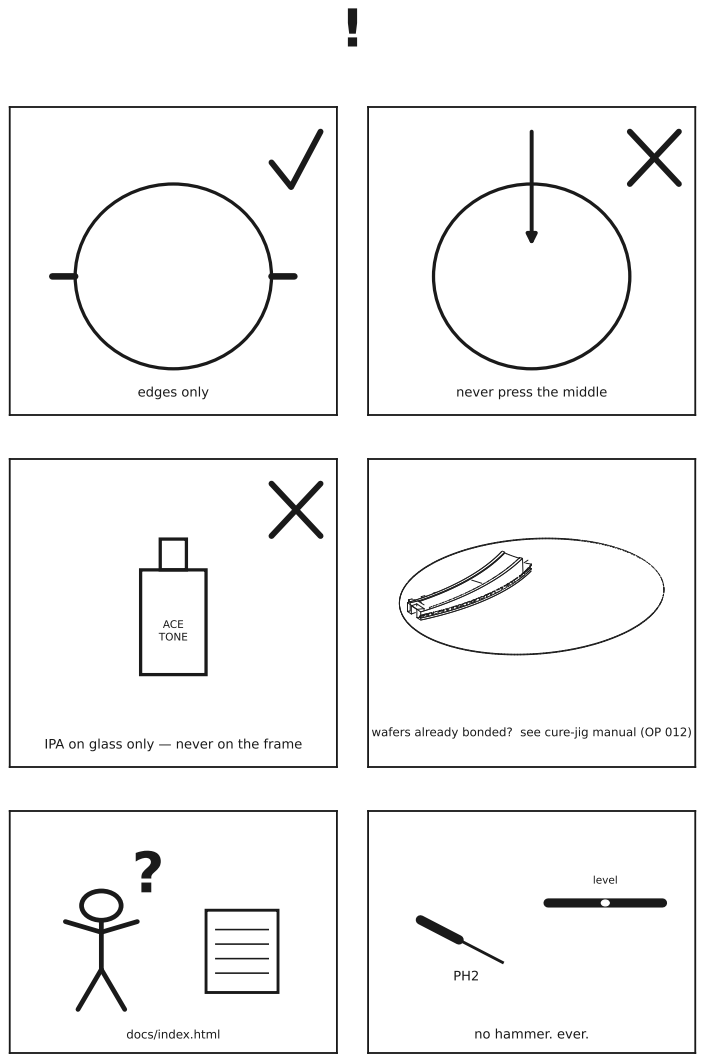
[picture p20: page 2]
edges only; never press the middle; ACE TONE; level

IPA on glass only — never on the frame

wafers already bonded? see cure-jig manual (OP 012)

docs/index.html

no hammer. ever.

×9

×9

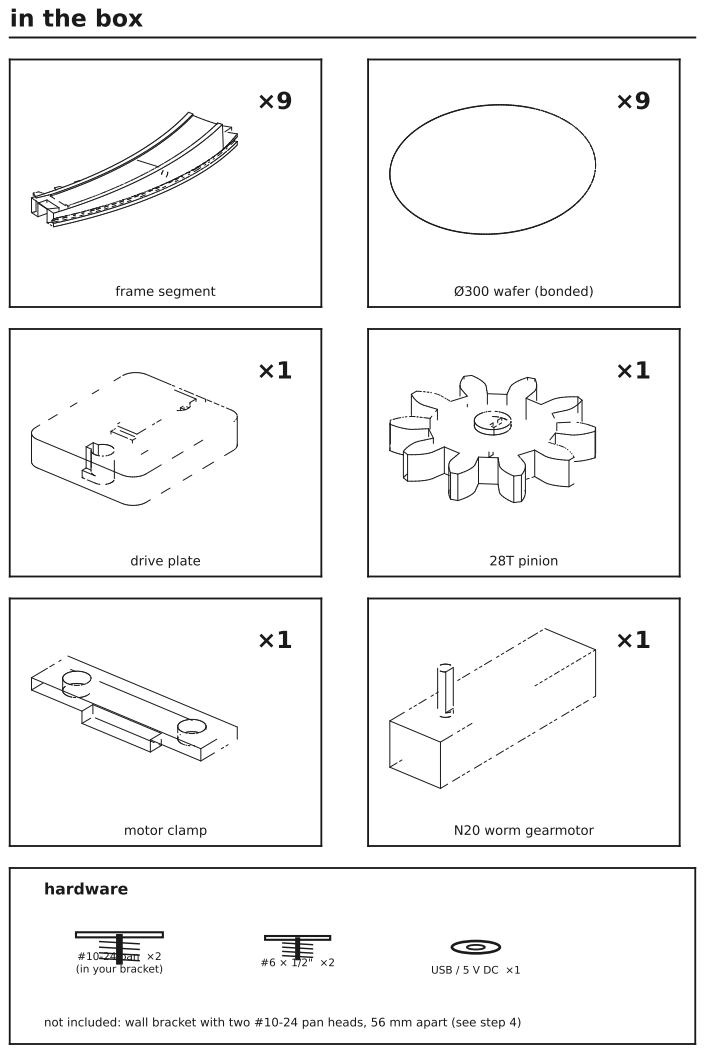
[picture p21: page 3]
frame segment; Ø300 wafer (bonded); drive plate; 28T pinion; motor clamp; N20 worm gearmotor; hardware; pan ×2; (in your bracket); USB / 5 V DC ×1

in the box

not included: wall bracket with two #10-24 pan heads, 56 mm apart (see step 4)

1

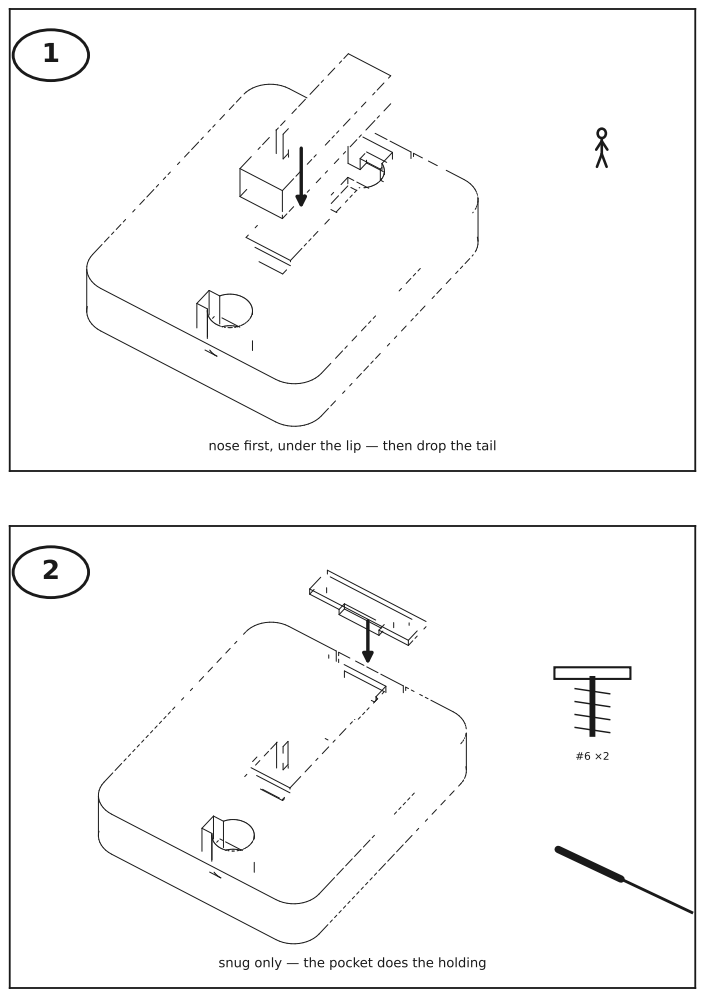
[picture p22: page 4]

nose first, under the lip — then drop the tail

snug only — the pocket does the holding

3

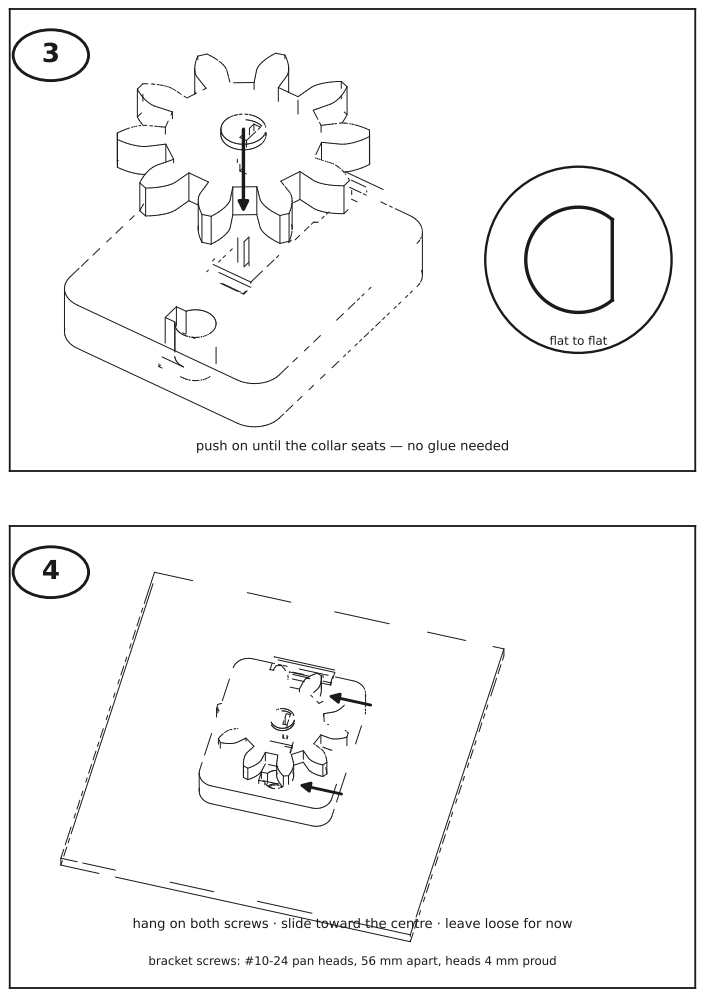
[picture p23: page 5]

flat to flat

push on until the collar seats — no glue needed

hang on both screws · slide toward the centre · leave loose for now

bracket screws: #10-24 pan heads, 56 mm apart, heads 4 mm proud

5
×9

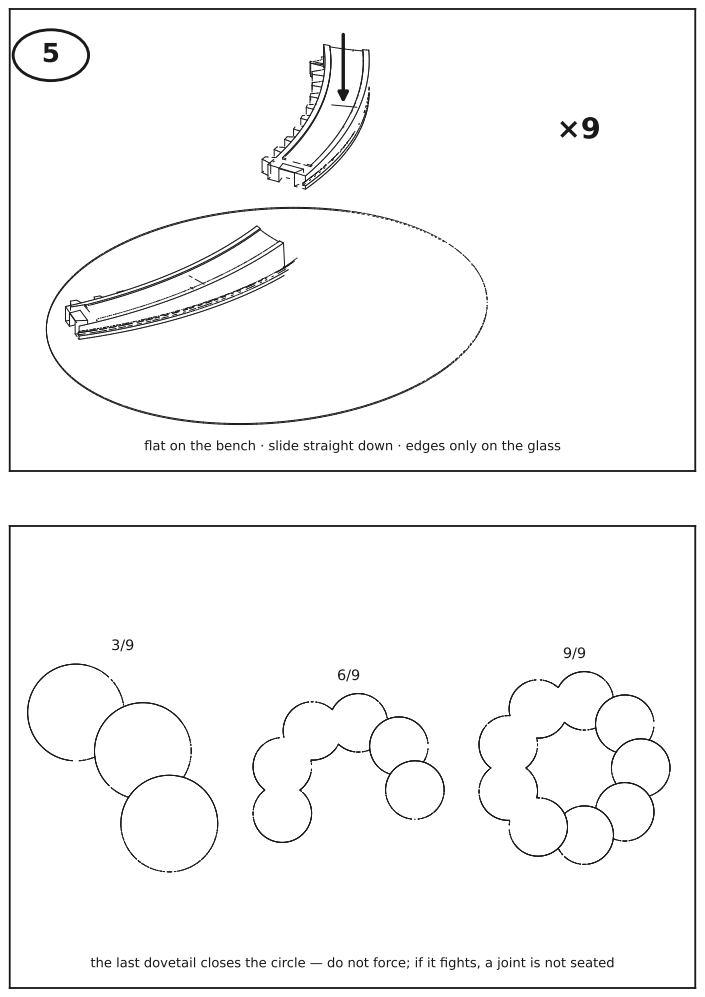
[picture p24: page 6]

flat on the bench · slide straight down · edges only on the glass

the last dovetail closes the circle — do not force; if it fights, a joint is not seated

6

×2

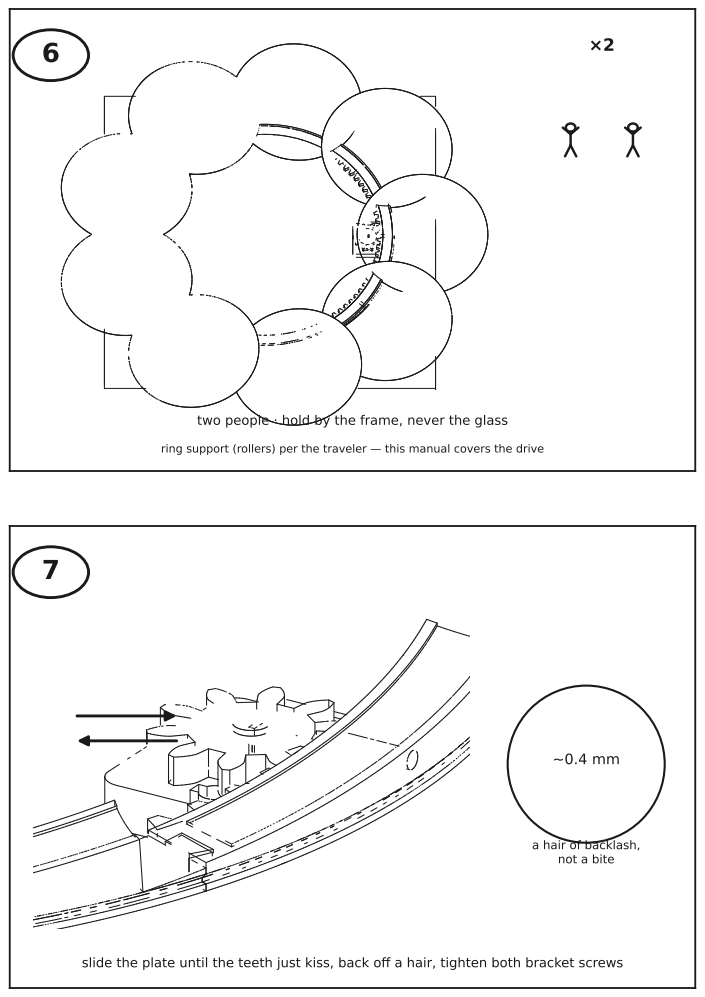
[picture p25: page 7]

two people · hold by the frame, never the glass

ring support (rollers) per the traveler — this manual covers the drive

a hair of backlash,
not a bite

slide the plate until the teeth just kiss, back off a hair, tighten both bracket screws

8

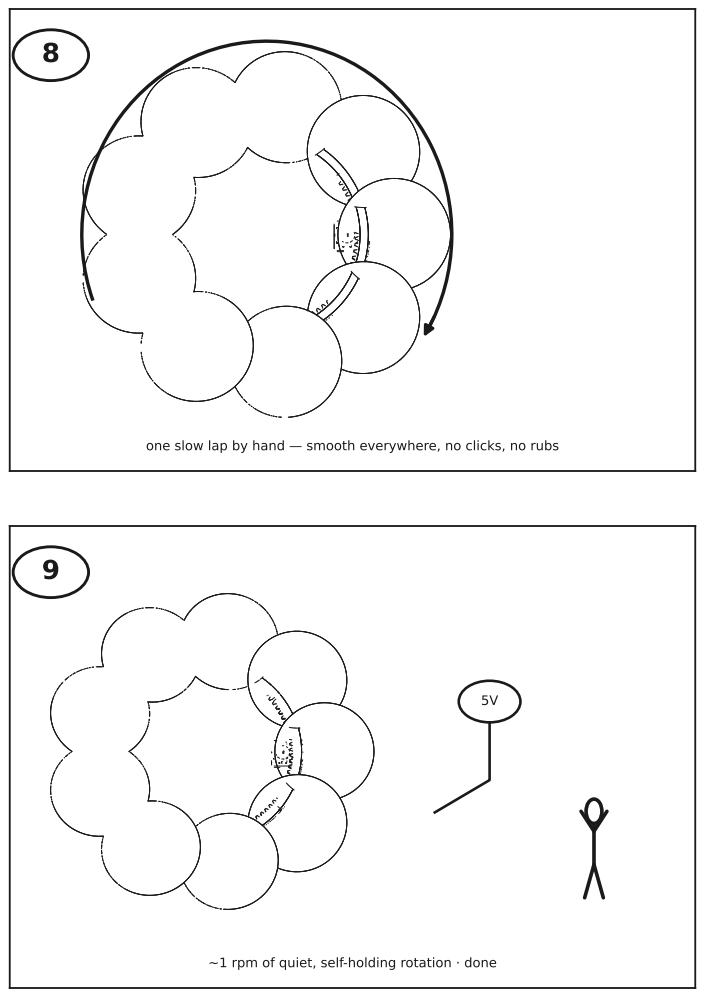
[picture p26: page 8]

one slow lap by hand — smooth everywhere, no clicks, no rubs

~1 rpm of quiet, self-holding rotation · done

# care

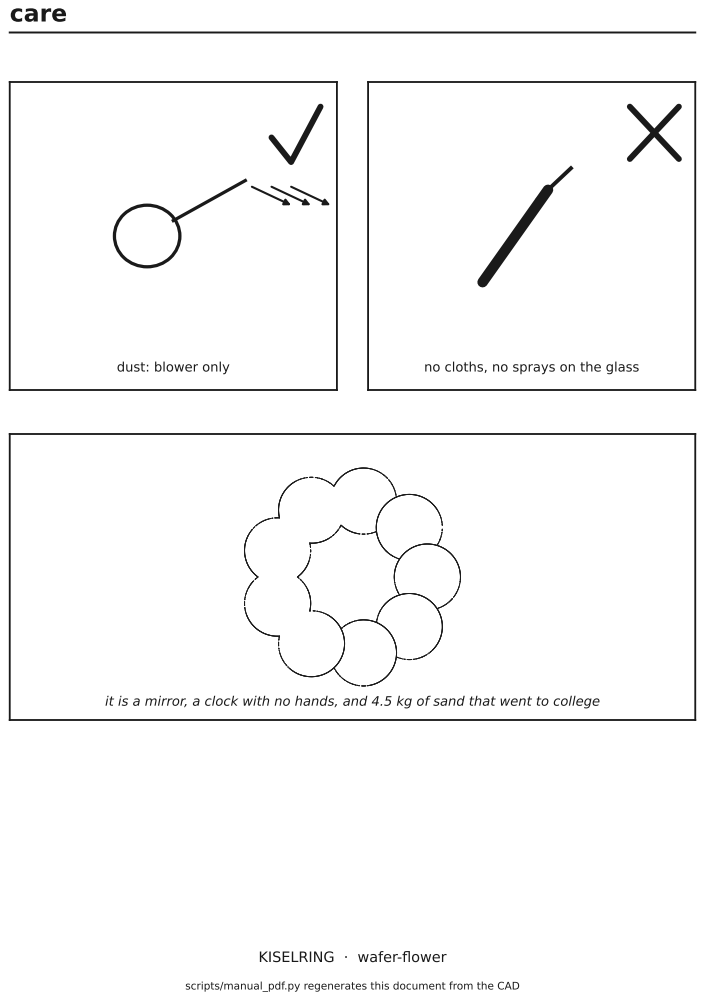
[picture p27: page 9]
dust: blower only; no cloths, no sprays on the glass

it is a mirror, a clock with no hands, and 4.5 kg of sand that went to college

KISELRING · wafer-flower

scripts/manual_pdf.py regenerates this document from the CAD

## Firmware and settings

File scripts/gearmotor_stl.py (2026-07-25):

#!/usr/bin/env python3
"""
Wafer Halo — low-profile gearmotor drive module.  ** PARKED 2026-07-24 **

PARKED: the drive train is filed away for now (Nick's call) and the ring
gear has since changed from the internal spur this module was designed
around to the FACE drive (segment_stl gear_drive='face', spur pinion on a
radial axis ~26 mm behind the wall face). This script therefore pins
gear_drive='spur' so it stays a self-consistent record of the old concept —
its checks run against the LEGACY spur ring, not the shipped segment. It is
no longer in CI. When the drive comes back, redesign around the face gear
(the pinion survives as-is; the worm-motor plate needs a new home ~26 mm
behind the ring and the static bracket reprinted at plate_t >= 32).

Drives the 252T module-2 INTERNAL ring gear (the flange on the frame's flat
bottom) with the existing 28T pinion at 9:1, from an N20-class micro WORM
gearmotor. Worm output means two things: the motor body lies FLAT against the
wall plate (output shaft perpendicular to the body, so the module is as thin
as the plate), and the drive self-holds when unpowered — no detent current.

The whole module hides BEHIND the frame: every static part except the pinion
stays behind the plane z_bot - 1 (the frame's flat bottom, minus running
clearance), so it adds ZERO front profile to the piece. Only the pinion
crosses that plane, and only inside r < g_tip except at the mesh itself.

    wall | bracket | [plate: motor sunk flush, clamp bar] | pinion | ring gear
                      <-------- plate_t + 1 mm ------->

Mount interface (to Nick's pre-installed wall bracket, which does not exist
in this repo yet): TWO KEYHOLE SLOTS at y = +/-key_y, hanging on #10-24
pan-head screws. The slots run RADIALLY (x, toward the halo axis) so the
plate slides to set gear mesh depth / backlash, then the screws are
tightened. The bracket only needs two screws at the spacing this script
prints, in the plane z = plate back face.

Motor: generic "N20 worm gearbox" DC gearmotor (the flat 6 V units with a
3 mm D-shaft sticking out of the gearbox face — Greartisan/uxcell-style,
ubiquitous online). ALL envelope dims below are parameters: measure the unit
you actually bought and override on the CLI before printing. Torque needed
at the pinion is ~3.3 mN.m (OP 015) — any N20 gearbox clears that by 2-3
orders of magnitude. Halo speed = motor output speed / 9, so a 10 rpm motor
turns the halo ~1.1 rpm; buy the output speed you want to look at.

Printed parts: drive_plate.stl, drive_clamp.stl, drive_pinion.stl.
View only:    drive_fitcheck.stl (plate + motor dummy + clamp + pinion +
              full frame ring + wafers).

Booleans prove, not assume (exit nonzero on FAIL): the ring and wafers swept
through a full tooth pitch against every static part, the pinion rolled
against the ring (conjugacy, co-rotating), pocket fit, clamp capture, shaft
engagement, keyhole geometry.

    pip install manifold3d
    python3 scripts/gearmotor_stl.py           # -> stl/
    python3 scripts/gearmotor_stl.py --help    # every param is a flag
"""
from __future__ import annotations
import math, os, sys, argparse

sys.path.insert(0, os.path.dirname(os.path.abspath(__file__)))
from segment_stl import (PARAMS, Cfg, prism, build_segment, build_wafer,
                         build_pinion, build_ring, check_mesh, write_stl,
                         report, rotated, Manifold, HAVE_MANIFOLD)

# ----------------------------------------------------------------------------
DRIVE = dict(
    # -- motor envelope: MEASURE YOUR UNIT, these are catalog-typical N20-worm
    mot_len   = 46.0,   # body length, along y (worm gearbox + can)
    mot_w     = 12.6,   # body width, along x
    mot_t     = 10.2,   # body thickness, along z (lies flat)
    shaft_d   = 3.0,    # output D-shaft diameter
    shaft_flat= 0.5,    # D-flat depth on the shaft
    shaft_len = 10.0,   # usable shaft length above the gearbox face
    shaft_off = 9.0,    # shaft axis distance from the FRONT (-y) end of the body
    # -- printed geometry
    plate_t   = 15.5,   # wall plate thickness (motor sinks in below flush)
    sink      = 2.0,    # motor top face recessed this far below the plate front
    plate_x2  = 34.0,   # plate half-length, x (radial)
    plate_y2  = 40.0,   # plate half-width, y (tangential)
    corner_r  = 8.0,    # plate corner radius
    gap       = 1.0,    # running clearance to the frame's flat bottom
    pock_clr  = 0.3,    # motor pocket clearance per side
    web_min   = 3.0,    # min web under the motor pocket
    clamp_t   = 2.0,    # clamp bar thickness (sits on the plate front face)
    clamp_w   = 8.0,    # clamp bar width (along y)
    clamp_scr = 2.9,    # clamp screw pilot bore (#6 x 1/2" self-tap into print)
    key_y     = 28.0,   # keyhole slots at y = +/-key_y
    key_entry = 11.0,   # keyhole entry hole diameter (#10 pan head drops in)
    key_slot  = 5.2,    # keyhole slot width (#10-24 shank slides)
    key_len   = 8.0,    # slot length = radial mesh adjustment range
    bore_clr  = 0.25,   # pinion bore oversize on the shaft diameter
    hub_d     = 12.0,   # pinion retention collar diameter
    hub_t     = 2.0,    # pinion retention collar height (below the teeth)
    wire_w    = 6.0,    # wire exit channel width, out the +y edge
)


class Drive:
    def __init__(self, cf, **kw):
        p = dict(DRIVE); p.update(kw); self.p = p
        for k, v in p.items(): setattr(self, k, v)
        self.cf = cf
        _, g = build_pinion(cf, bore=0.0, flat=0.0)
        self.g = g                              # rp, rb, ra, rf, T of the pinion
        self.cx = cf.g_pitch - g['rp']          # pinion axis x: centre distance
        # z stack, wall side is -z. Pinion face spans the ring flange exactly.
        self.z_ring0 = cf.z_bot                 # ring teeth bottom
        self.z_ring1 = cf.z1                    # ring teeth top
        self.z_front = cf.z_bot - self.gap      # plate front face
        self.z_back  = self.z_front - self.plate_t
        # motor sunk BELOW flush by `sink`, so the retention lip and the clamp
        # feet both stay behind the plate front plane
        self.pock_z  = self.z_front - (self.mot_t + 0.2 + self.sink)
        # shaft base sits on the motor top face; engagement into the pinion bore
        self.shaft_z0 = self.pock_z + 0.2 + self.mot_t
        self.shaft_z1 = self.shaft_z0 + self.shaft_len
        self.engage   = self.shaft_z1 - cf.z_bot   # bore starts at the teeth
        web = self.pock_z - self.z_back
        assert web >= self.web_min, f"pocket web {web:.1f} < {self.web_min}"


# ---- solid helpers ----------------------------------------------------------
def box(x0, x1, y0, y1, z0, z1):
    return prism([(x0, y0), (x1, y0), (x1, y1), (x0, y1)], z0, z1 - z0)


def zcyl(r, z0, h, cx=0.0, cy=0.0, fn=96):
    return Manifold.cylinder(h, r, r, fn).translate([cx, cy, z0])


def rounded_rect(x0, x1, y0, y1, r, n=12):
    """CCW rounded-rectangle profile."""
    cs = [(x1 - r, y1 - r, 0.0), (x0 + r, y1 - r, 90.0),
          (x0 + r, y0 + r, 180.0), (x1 - r, y0 + r, 270.0)]
    pts = []
    for cx, cy, a0 in cs:
        for i in range(n + 1):
            a = math.radians(a0 + 90.0 * i / n)
            pts.append((cx + r * math.cos(a), cy + r * math.sin(a)))
    return pts


# ---- parts ------------------------------------------------------------------
def build_motor_dummy(d):
    """Envelope solid for interference checks and the fitcheck view: body box
    lying flat, shaft up. Front (-y) end carries the worm gearbox and shaft."""
    m = (box(d.cx - d.mot_w / 2, d.cx + d.mot_w / 2,
             -d.shaft_off, d.mot_len - d.shaft_off,
             d.pock_z + 0.2, d.shaft_z0)
         + zcyl(d.shaft_d / 2, d.shaft_z0, d.shaft_len, d.cx, 0.0)
         - box(d.cx + d.shaft_d / 2 - d.shaft_flat, d.cx + d.shaft_d,
               -d.shaft_d, d.shaft_d, d.shaft_z0 + 1.0, d.shaft_z1 + 1.0))
    return m


def build_plate(d):
    cf = d.cf
    pl = prism(rounded_rect(d.cx - d.plate_x2, d.cx + d.plate_x2,
                            -d.plate_y2, d.plate_y2, d.corner_r),
               d.z_back, d.plate_t)
    # motor pocket, open on the front face
    c = d.pock_clr
    pl -= box(d.cx - d.mot_w / 2 - c, d.cx + d.mot_w / 2 + c,
              -d.shaft_off - c, d.mot_len - d.shaft_off + c,
              d.pock_z, d.z_front + 1.0)
    # wire exit channel out the +y edge, in the pocket floor
    pl -= box(d.cx - d.wire_w / 2, d.cx + d.wire_w / 2,
              0.0, d.plate_y2 + 1.0, d.pock_z, d.pock_z + 4.0)
    # retention lip over the gearbox (-y) end of the pocket: the motor slides
    # nose-first under it, then the tail drops. 0.1 above the motor top, and
    # entirely behind the plate front plane. Prints as a 14 mm bridge.
    pl += box(d.cx - d.mot_w / 2 - c - 0.5, d.cx + d.mot_w / 2 + c + 0.5,
              -d.shaft_off - c - 0.4, -d.shaft_off + 3.0,
              d.shaft_z0 + 0.1, d.z_front)
    # keyhole slots: entry at the OUTER (+x) end, slot runs -x so sliding the
    # plate toward the halo axis deepens the mesh. The #10 pan head rides in a
    # groove opening on the BACK face (between plate and bracket).
    for s in (1.0, -1.0):
        ex = d.cx + d.key_len / 2
        pl -= zcyl(d.key_entry / 2, d.z_back - 1.0, d.plate_t + 2.0, ex, s * d.key_y)
        pl -= box(ex - d.key_len, ex, s * d.key_y - d.key_slot / 2,
                  s * d.key_y + d.key_slot / 2, d.z_back - 1.0, d.z_front + 1.0)
        pl -= box(ex - d.key_len, ex, s * d.key_y - d.key_entry / 2,
                  s * d.key_y + d.key_entry / 2, d.z_back - 1.0, d.z_back + 4.0)
    # clamp screw pilots, in solid plate just outside the pocket walls
    for s in (1.0, -1.0):
        pl -= zcyl(d.clamp_scr / 2, d.z_front - 12.0, 13.0, d.cx + s * d.clamp_dx(),
                   d.clamp_cy())
    return pl


def _clamp_dx(d):
    return d.mot_w / 2 + d.pock_clr + 4.0


def _clamp_cy(d):
    # bar centre: past the pinion swing circle (ra + margin), still on the can
    return max(d.g['ra'] + 0.6 + d.clamp_w / 2 + 0.4,
               d.mot_len - d.shaft_off - d.clamp_w / 2 - 1.0 - 4.0)


Drive.clamp_dx = _clamp_dx
Drive.clamp_cy = _clamp_cy


def build_clamp(d):
    """Bar across the tail of the motor can, screwed to the plate with two
    #6 x 1/2" self-taps. It sits ON the plate front face, entirely OUTSIDE the
    pinion's swing circle (the gearbox end is held by the plate's printed
    lip); its feet drop through the pocket opening onto the motor body."""
    cy, dx = d.clamp_cy(), d.clamp_dx()
    bar = box(d.cx - dx - 5.0, d.cx + dx + 5.0, cy - d.clamp_w / 2,
              cy + d.clamp_w / 2, d.z_front, d.z_front + d.clamp_t)
    bar += box(d.cx - d.mot_w / 2, d.cx + d.mot_w / 2, cy - d.clamp_w / 2,
               min(cy + d.clamp_w / 2, d.mot_len - d.shaft_off),
               d.shaft_z0, d.z_front + 1.0)
    for s in (1.0, -1.0):
        bar -= zcyl(2.0, d.shaft_z0 - 1.0, d.mot_t + d.sink + d.clamp_t + 4.0,
                    d.cx + s * dx, cy)
    return bar


def build_drive_pinion(d):
    """The mating 28T pinion with a D-bore for the motor shaft and a grip
    collar ABOVE the teeth (a spur mesh has no axial force component, so the
    pinion only needs friction on the D-flat to stay put; the collar gives
    bore length and something to press on). Teeth span the ring flange."""
    cf = d.cf
    bore = d.shaft_d + d.bore_clr
    pin, _ = build_pinion(cf, bore=0.0, flat=0.0)
    hub = zcyl(d.hub_d / 2, cf.tmin, d.hub_t, 0.0, 0.0)
    pin += hub
    pin -= zcyl(bore / 2, -1.0, cf.tmin + d.hub_t + 2.0)
    pin -= prism([(bore / 2 - d.shaft_flat, -bore), (bore / 2 - d.shaft_flat, bore),
                  (bore, bore), (bore, -bore)], -1.0, cf.tmin + d.hub_t + 2.0)
    return pin.translate([d.cx, 0.0, cf.z_bot])   # assembly position


# ---- verification -----------------------------------------------------------
def run_checks(d, plate, clamp, motor, pinion, frame_parts, wafers):
    EPS = 1e-6
    cf = d.cf
    statics = plate + clamp + motor
    ok = True
    zero, hit = [], []

    # the ring is 9-fold symmetric with tps teeth/segment: sweeping ONE tooth
    # pitch covers every angular phase the frame can ever present
    pitch_deg = 360.0 / cf.teeth
    worst_f = worst_w = 0.0
    for i in range(5):
        a = pitch_deg * i / 4.0
        fr = sum((p.rotate([0, 0, a]) for p in frame_parts), Manifold())
        wf = sum((p.rotate([0, 0, a]) for p in wafers), Manifold())
        worst_f = max(worst_f, (fr ^ statics).volume())
        worst_w = max(worst_w, (wf ^ statics).volume())
    zero.append((f'frame swept 1 tooth pitch vs plate+clamp+motor', worst_f))
    zero.append((f'wafers swept 1 tooth pitch vs plate+clamp+motor', worst_w))

    # pinion spin envelope: tip cylinder over the full part height
    spin = zcyl(d.g['ra'] + 0.6, cf.z_bot - 0.5,
                d.cf.tmin + d.hub_t + 1.0, d.cx, 0.0, fn=256)
    zero.append(('pinion spin envelope vs plate+clamp', (spin ^ (plate + clamp)).volume()))
    zero.append(('pinion vs motor body', (pinion ^ motor).volume()))
    zero.append(('motor vs pocketed plate', (motor ^ plate).volume()))
    zero.append(('clamp vs plate', (clamp ^ plate).volume()))

    # mesh conjugacy, both directions of the roll (internal pair co-rotates)
    mesh = check_mesh(cf)
    zero.append((f"pinion/ring roll, 1 tooth pitch (centre {mesh['centre']:.0f})",
                 mesh['worst_overlap']))

    frame0 = sum(frame_parts, Manifold())
    hit.append(('pinion tip circle reaches into the ring teeth',
                (spin ^ frame0).volume(), True))
    hit.append(('clamp captures the motor (motor +1 z contacts)',
                (motor.translate([0, 0, 1.0]) ^ clamp).volume(), True))
    hit.append(('motor seated (motor -1 z contacts pocket floor)',
                (motor.translate([0, 0, -1.0]) ^ plate).volume(), True))

    print("  interference (must all be 0 mm3):")
    for name, v in zero:
        good = v < EPS; ok &= good
        print(f"    {'PASS' if good else 'FAIL':4}  {name:52} {v:10.4f}")
    print("  capture / engagement (contact where expected):")
    for name, v, want in hit:
        good = (float(v) > EPS) == want; ok &= good
        print(f"    {'PASS' if good else 'FAIL':4}  {name:52} {float(v):10.4f}")

    # scalar gates
    print("  scalars:")
    scal = [
        ('shaft engagement into pinion bore >= 6.5 mm', d.engage, d.engage >= 6.5),
        ('pocket web under motor >= web_min', d.pock_z - d.z_back,
         d.pock_z - d.z_back >= d.web_min),
        ('keyhole entry passes a #10 pan head (Ø>=9.5)', d.key_entry,
         d.key_entry >= 9.5),
    ]
    for name, v, good in scal:
        ok &= good
        print(f"    {'PASS' if good else 'FAIL':4}  {name:52} {v:10.2f}")
    return ok


def main():
    if not HAVE_MANIFOLD:
        sys.exit("needs manifold3d for STL output:  pip install manifold3d")
    ap = argparse.ArgumentParser(description="Wafer Halo — gearmotor drive module")
    ap.add_argument('-o', '--out', default='stl')
    for k, v in {**PARAMS, **DRIVE}.items():
        ap.add_argument(f'--{k}', type=type(v), default=None)
    a = ap.parse_args()
    kw = {k: getattr(a, k) for k in PARAMS if getattr(a, k) is not None}
    kw.setdefault('gear_drive', 'spur')   # PARKED: legacy spur ring (see header)
    print('*** PARKED module: models the LEGACY internal-spur drive, not the '
          'shipped face-gear segment ***\n')
    cf = Cfg(**kw)
    d = Drive(cf, **{k: getattr(a, k) for k in DRIVE if getattr(a, k) is not None})
    os.makedirs(a.out, exist_ok=True)

    print(f"Gearmotor drive  ·  {d.g['T']}T pinion / {cf.teeth}T internal ring = "
          f"{cf.teeth / d.g['T']:.0f}:1  ·  axis at r={d.cx:.0f}")
    print(f"  z stack  ring flange {d.z_ring0:.1f}..{d.z_ring1:.1f}  plate front "
          f"{d.z_front:.1f}  back (bracket face) {d.z_back:.1f}")
    print(f"  profile  module hides behind the frame: only the pinion crosses "
          f"z_bot, wall standoff = plate_t + gap = {d.plate_t + d.gap:.0f} mm + bracket")
    print(f"  mount    two #10-24 keyholes at ({d.cx + d.key_len / 2:.0f}, "
          f"+/-{d.key_y:.0f}), {d.key_len:.0f} mm radial adjustment")
    print(f"  motor    N20-worm envelope {d.mot_len:.0f}x{d.mot_w:.1f}x{d.mot_t:.1f}, "
          f"Ø{d.shaft_d} D-shaft — MEASURE YOURS, override on the CLI")
    print(f"  drive    needs ~3.3 mN.m at the pinion (OP 015); halo rpm = motor "
          f"rpm / {cf.teeth / d.g['T']:.0f}\n")

    plate  = build_plate(d)
    clamp  = build_clamp(d)
    motor  = build_motor_dummy(d)
    pinion = build_drive_pinion(d)
    frame  = build_ring(cf)
    wafers = [build_wafer(cf, k) for k in range(cf.N)]

    ok = run_checks(d, plate, clamp, motor, pinion, frame, wafers)
    print()

    dz = -d.z_back
    outs = [('drive_plate.stl',  [plate.translate([-d.cx, 0, dz])], 'prints back face down'),
            ('drive_clamp.stl',  [clamp.translate([-d.cx, 0, -d.z_front])
                                  .rotate([180.0, 0.0, 0.0])], 'prints top face down'),
            ('drive_pinion.stl', [pinion.translate([-d.cx, 0, -cf.z_bot])],
             'prints teeth down, collar up'),
            ('drive_fitcheck.stl', frame + wafers + [plate, clamp, motor, pinion],
             'view only, full assembly')]
    for fname, solids, note in outs:
        bodies = write_stl(solids, os.path.join(a.out, fname))
        v = report(fname, solids, bodies, note)
        if 'fitcheck' not in fname:
            print(f"{'':24}mass  45% infill {v*1.27e-3*0.45:6.1f} g   "
                  f"solid {v*1.27e-3:6.1f} g")

    print(f"\n{'ALL CHECKS PASS' if ok else 'CHECK FAILURES ABOVE — do not print'}")
    print(f"Wrote to {os.path.abspath(a.out)}/")
    return 0 if ok else 1


if __name__ == '__main__':
    sys.exit(main())

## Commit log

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2026-07-20 In progress
    [01_band.dxf, 02_slab.dxf, 03_socket.dxf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]
2026-07-21 Add OP 012 cure jig: through keyhole, centring fences, full drivetrain
    Two printed fences slide toward each other on a #10-24 rod passed
    radially THROUGH the segment keyhole (Rev B.3: hole_dep 15->30.5, axis
    raised to z1+2.6 so rod-end hardware can rotate over the bench; gear
    teeth untouched, land unbroken). Tightening seats both fences on the
    segment - the wafer floats edge-captured at +/-0.15 x / ~+/-0.30 y with
    zero clamp load. Rod, captive nut, washer and wing nut are modelled and
    boolean-checked (18 checks) in scripts/cure_jig_stl.py; illustrated
    plain-language instructions in docs/cure-jig.html with renders and MP4s
    generated from the CAD by scripts/cure_jig_media.py. Also tracks
    slice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
    [cure_jig_fitcheck.stl, cure_jig_inboard.stl, cure_jig_knob.stl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]
2026-07-22 More CAD
    [my_frame_segment.stl]
2026-07-22 Move my_frame_segment.stl into stl/
    [my_frame_segment.stl]
2026-07-22 Add real-STL CAD viewer to Pages with CI-gated configuration checks
    Pages serves master:/docs only, so nothing in stl/ ever reached the site,
    and index.html re-derives its 3D view instead of loading the CAD. Now
    scripts/viewer_export.py exports every body in scene coordinates to
    docs/models/ plus a manifest (motion vectors, colors, check results), and
    docs/viewer.html shows the actual solids: jig add/remove, open/close
    stroke, wafer placement drop, glued ring station by station, y-section
    plane, and the check results as a PASS/FAIL panel.
    Every configuration is gated in Python first: the 18-check cure-jig
    nominal suite, the fence/rod strokes swept in 5 steps against segment and
    wafer, the w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
    [hex_nut.stl, jig_inboard.stl, jig_outboard.stl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]
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2026-07-22 Pass my_frame_segment.stl through to the viewer as an OnShape overlay
    Nick's call: it will be exported in the same orientation as segment.stl.
    viewer_export.py copies it byte-for-byte into docs/models/ (group
    'onshape'), computes stats straight off the binary, and WARNS — never
    gates — while the current export is still in OnShape's own frame. The
    viewer grows an OnShape toggle (semi-transparent teal, off by default)
    that will overlay the script segment exactly once the re-export lands.
    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
    [my_frame_segment.stl]
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2026-07-23 Add low-profile gearmotor drive module + OCC-verified STEP export
    Drive module (scripts/gearmotor_stl.py): N20-class worm gearmotor on a
    wall plate turning the existing 28T pinion (3 mm D-bore, collar above the
    teeth) against the 252T internal ring at 9:1. Everything but the pinion
    hides behind the frame's flat bottom; worm gearing self-holds unpowered.
    Mounts on two #10-24 pan heads via keyhole slots with 8 mm of radial
    backlash adjustment. 14 self-checks (ring+wafers swept one tooth pitch,
    pinion spin envelope, mesh roll, capture/engagement); CI now runs it.
    STEP export (scripts/step_export.py, reinstated per Nick 2026-07-22 for
    viewing/archival): planar B-rep AP214 with coplanar-face mer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
    [drive_clamp.stl, drive_clamp.stp, drive_fitcheck.stl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]
2026-07-23 Add KISELRING IKEA-style assembly manual rendered from the CAD
    scripts/manual_pdf.py -> docs/kiselring-manual.pdf: 9 A4 pages, every 3D
    panel line-art rendered from the real solids (orthographic projection,
    z-buffer hidden-line removal, silhouette + crease edges only), IKEA
    grammar throughout — pictogram warnings, in-the-box inventory, numbered
    steps, backlash detail circle, care page. Covers motor install through
    power-on; wafer bonding stays with the cure-jig doc, wall bracket noted
    as not included. CLAUDE.md documents the three new scripts; TODO.md
    carries the open bracket/motor-envelope questions.
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2026-07-25 M6 keyhole + slimmed cure jig + printable M5/M6 hardware
    Keyhole: Ø5 (#10-24) -> Ø6.5 (M6 clearance; an M6 rod slides through
    as printed, no reaming). keyhole_z() now derives from the bore radius
    (z1 + hole_r + 0.1), keeping the bore bottom exactly 0.1 mm above the
    gear flange at any size — axis moves 12.6 -> 13.35 mm above the bench,
    web under the adhesive pocket floor 2.4 -> ~0.9 mm (unloaded; genus 1
    proves unbroken). Segment 94.3 -> 93.9 cm3, sliced 66.0 -> 65.5 g.
    Cure jig on M6 hardware: rod Ø6.0, ISO nut AF 10 / 5.2 thick, M6
    washer. An M6 WING NUT IS OUT — it swings ~15 mm and the axis clears
    the bench by only 13.35 (and cannot rise without the bore breaking
    into the pocket);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
    [cure_jig_fitcheck.stl, cure_jig_inboard.stl, cure_jig_knob.stl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]
2026-07-25 Face-gear ring drive + static wall bracket; gearmotor parked
    RING GEAR -> FACE GEAR (segment_stl gear_drive='face'): the 252 teeth
    become axial slots in the flange's wall face (band r248-256, 4.5 deep,
    rack-form flanks, 1.6 mm mouth flare for the pinion tip trochoids), so
    the unchanged 28T spur pinion drives on a RADIAL axis 26 mm behind the
    wall face — motor flat against the wall, perpendicular to the halo
    axis, which is the requirement behind Nick's 45-degree ask. The literal
    45/45 pair was built and measured first: at 9:1 with 90-degree shafts a
    true bevel needs 83.7/6.3 cones, and the forced 45-degree internal cone
    shows 276-386 mm3 of phase-independent curvature interference against
    a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
    [02_slab.dxf, 05_face_slot.dxf, 05_ring_teeth.dxf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]
2026-07-25 Viewer works from file://: base64 model bundle fallback
    Double-clicking docs/index.html failed with 'serve over http' because
    fetch() is blocked under file://. viewer_export.py now also emits
    docs/models/models_data.js — a single base64 bundle of the manifest +
    every part STL (1.2 MB) — and the viewer falls back to loading it via
    <script src>, which file:// does allow. The fetch path stays primary
    (Pages users keep the lean per-file loads), the STLs stay authoritative
    and GitHub-previewable, and --verify byte-gates the bundle against the
    committed manifest + STLs so it can't go stale.
    Playwright-verified: index.html and viewer.html both load 12/12 checks
    under file://, and the http fetc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
2026-07-25 Generated 45-deg bevel ring teeth + one live parametric hub visual
    GEAR (Nick overriding the face-slot call: teeth must start at the wafer
    side and drop at 45 deg toward the mounting wall): the 252 teeth now
    live on a 45-deg cone, tips r250 (front) -> r260 (wall face), and they
    are GENERATED, not drawn — ideal involutes on 45/45 cones at 9:1 with
    90-deg shafts bind (276-386 mm3 measured), so the module-matched 45-deg
    coned pinion (m_eff 2.397 at mid-cone) is swept through the meshing
    motion in CSG (61 positions, +/-2 pitches) and subtracted from a coned
    blank. The runner is the cutter thinned by gear_bl=0.6, so interference
    is impossible by construction: the roll sweep measures 0.034 mm3 o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
    [02_slab.dxf, 05_bevel_cutter.dxf, 05_face_slot.dxf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]
2026-07-25 Hub visual renders the SHIPPED CAD at Rev B.3; schematic only off-preset
    Nick's report: the hub render looked nothing like the stl/ folder. Two
    causes: the page booted at the old traveler slider values (so the first
    render was a DIFFERENT design than the shipped one), and my box-art
    approximations of the cure jig and saddles were crude to the point of
    garbage.
    Fix: the calculator now boots at the shipped Rev B.3 parameters and,
    whenever the sliders sit exactly there, renders the REAL STLs from the
    models_data.js bundle — byte-identical to stl/: segment with the
    generated 45-deg teeth, dovetail and groove; the actual cure-jig fences
    + rod + knob in the (new bench-angle) jig view; the actua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
    [saddle_l.stl, saddle_r.stl]
2026-07-25 Module-4 bevel teeth: 126T ring / 14T pinion, real gear presence
    Nick: the module-2 teeth (252T, 4.5 mm deep on a Ø504 ring) look
    insignificant — he wants proper mixer-style 45-deg bevel gears. Module
    doubled to 4: 14 teeth/segment = 126T at the SAME Ø504 pitch, same
    exact 9:1 with the 14T coned pinion (same 28 mm pitch radius, ~Ø77 big
    end), teeth 9 mm deep — reads as a real bevel gear set. Chunkier still
    is one flag away (--gear_m 5.6 -> 90T/10T).
    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
    [02_slab.dxf, 05_bevel_cutter.dxf, 06_pinion.dxf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]
2026-07-25 True spiral bevel: 90T ring / 10T pinion, m5.6 x 35-deg spiral
    Nick: the m4 teeth are 'little nubbins' — he wants a true spiral bevel
    (and DESIGN.md, recovered onto this branch, says the same: 'spiral
    bevel rack on the inner radius'). Delivered by extending the generation
    machinery, not by drawing spirals: the cutter pinion is ONE extrusion
    with taper AND twist (tan(35 deg) of circumferential advance across the
    face at the matched pitch), and sweeping it through the meshing motion
    generates the conjugate SPIRAL ring teeth automatically — tip relief,
    backlash and all. Mesh sweep: 0.000 mm3, still gating the exit.
    Module up to 5.6: 10 teeth/segment = 90T at the same O504 pitch, same
    exact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
    [02_slab.dxf, 05_bevel_cutter.dxf, 06_pinion.dxf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]
2026-07-25 Cure jig: peg capture — X/Y only, gravity owns Z
    Nick's call: drop the wall-arc cutouts (coplanar slot, lips, wings) and
    capture the wafer with a couple of pegs per side instead — constrain X
    and Y, let gravity handle Z, keep the jig part-agnostic and never
    overconstrained.
    Each fence now carries TWO Ø8 chamfered pegs at ±22° off the radial
    meridian, flanks at projected-rim + 0.15. The projection matters: the
    tilted wafer's plan rim is an ELLIPSE (y semi-axis r·cosθ, 0.57 mm shy
    of r at θ=5), and pegs placed on a plain r+slack circle measured a 0.23
    gap at 22° with the y-window drifting by tilt — deriving each peg's
    radius from the ellipse keeps flank gap = slack for any wafer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
    [cure_jig_fitcheck.stl, cure_jig_inboard.stl, cure_jig_outboard.stl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]
2026-07-25 Outer drive: external straight bevel gear + inner idler groove + top bracket
    Drive rethink (Nick): the ring now HANGS on two grooved idler wheels and
    is driven purely rotationally from the top by a single wall bracket.
    - segment_stl.py: gear moves OUTSIDE the band onto a web — 108T external
    45-deg bevel, module 5.6, 12T/segment, big-at-front (tips r318 wafer
    side -> r308 at wall; the only orientation whose working face points
    outward-and-back where the bracket pinion lives). STRAIGHT teeth
    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
    [02_slab.dxf, 05_bevel_cutter.dxf, 06_pinion.dxf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]
2026-07-25 Gear band face 4.5 mm: clear the neighbour-wafer cut, gate it forever
    The first outer-drive build shipped a tmin-tall (10 mm) tooth band. The
    MANDATORY neighbour-wafer clearance cut (Rev B, never remove) dips to
    z_bot+4.86 over the leading ~15-20 deg of the sector — its rim crosses
    the tooth annulus at a~14.6 — so it planed the last two teeth to half
    height ("multiple heights") and left fin slivers where the disc rim
    crossed a tooth at a grazing angle ("a strand"). The inner gear at
    r<=255 never touched that plane; the external one does. Generation was
    already fully deterministic (regen was byte-identical to the shipped
    STL) — this was a design collision, not flaky CSG.
    - segment_stl.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
    [05_bevel_cutter.dxf, bracket_plate.stl, bracket_plate.stp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]
2026-07-25 Beveloid drive: flush root, radial tip relief, axial pinion from the top
    Three fixes from Nick's review of the outer drive, plus a fourth found on
    the way in:
    1. NO GAP band-to-teeth: tooth count is quantised in steps of N, so the
    module is retuned (5.6 nominal -> 5.384 effective, gear_m_nom keeps
    the input) to land the front root circle 1 mm inside the band OD —
    teeth rise straight off the band's outer wall, and build_segment
    carves the band's outer 1.5 mm over the gear face so the spaces cut
    into the band edge instead of being filled back to full height.
    2. NO RING at the teeth edge: tip relief is now RADIAL (cutter advanced
    dr=-0.3 toward the ring) instead of the old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
    [05_bevel_cutter.dxf, 06_pinion.dxf, bracket_plate.stl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]
2026-07-25 Drive view with live rotation + double the bracket standoff for the motor
    - Calculator (hub + engineering): new "Drive" view — full ring + wafers +
    bracket with the plate ghosted so the drivetrain shows: N20 mock +
    beveloid pinion on top, the two grooved idler wheels below on the bore.
    The ring auto-rotates (~1 rpm); the pinion counter-rotates at the true
    9:1 and the wheels spin up at Ri/wheel_R (~10.6x), so the mesh visibly
    runs. Camera presets to a behind-top orbit (the wafers hide the
    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
    [bracket_plate.stl, bracket_plate.stp]
2026-07-25 Dovetail height 10 -> 5 mm (new dt_h param): tail read too thick to print
    The male dovetail was a full-slab-height (tmin=10) prism. New dt_h=5
    trims the MALE tail only — everything beyond the +half radial face plane
    above dt_h is cut away — while the female socket stays tmin-deep, so
    segments still slide together in Z and the joint fit is unchanged
    (assembled-pair interference 0.0000, T1 clearance untouched).
    Statics: S_joint = dt_h*16^2/6 = 213 mm3 (was 427). On the RETIRED
    single-point-hang case that reads 2.2x; the shipped two-point idler hang
    has M well under it, margin >3x. Calculator S_joint now uses DT_H.
    All gates re-pass: segment (mesh 0.00000, zero-trim, genus 1), bracket
    9/9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
    [cure_jig_fitcheck.stl, segment.stl, segment_pair.stl]
2026-07-25 Socket cut dt_h+0.5 tall: the tmin-tall cutout's roof was unprintable
    Round two of the dovetail fix — Nick meant the CUTOUT, not the tail: the
    female socket was cut tmin (10) tall, leaving its roof under 0.5 mm at
    the trailing edge where the band is thinnest. The socket is now
    dt_h + 0.5 tall (5.5): the male (dt_h = 5) still enters with 0.5 mm of
    headroom, both features stay open at the flat bottom (segments slide
    together in Z as before), and the roof measures 5.36 mm — printable.
    Assembled-pair interference 0.0000.
    Side effect: the adhesive-pocket punch-through hazard the pocket inset
    guarded against is gone (~4.5 mm now under the pocket floor); the inset
    stays for the OP 015 centroid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
    [cure_jig_fitcheck.stl, segment.stl, segment_pair.stl]
2026-07-26 Simplify the generation: shared helpers, memoized sweep, derived constants
    /simplify pass over the CAD scripts (4-angle review: reuse, simplification,
    efficiency, altitude). Geometry-identical by construction where possible;
    where boolean ORDER changed (tree-reduce) the solids re-verify through
    every gate. segment_stl.py wall time drops ~4x (one 151-step generation
    sweep per run instead of seven, tree-reduced instead of quadratic).
    Efficiency
    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
    [cure_jig_fitcheck.stl, cure_jig_inboard.stl, cure_jig_outboard.stl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]
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2026-07-26 OnShape workflow guide page: install, use, mate, collaborate
    docs/onshape-guide.html — a detailed walkthrough of the FeatureScript
    system for OnShape users: Feature Studio install, both feature dialogs
    with the B.3 defaults, the boolean-union convention, assembly mating
    (parallel axes at C=325.53, gear relation 9:1 reversed), the spiral
    option and why the build ships straight, the two constraints OnShape
    can't see (gear_F ceiling, tooth-count divisibility) with the Python
    gates as authority, and the collaboration loop (document sharing,
    Feature Studio versioning, cross-document feature links, branching,
    and the repo round-trip via my_frame_segment.stl).
    Own visual identity (Archivo expand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
2026-07-26 Deep bevel: gear face 4.5 -> 9.5 — the 45-degree cone Nick dreamed of
    The 4.5 mm face read as stubby spur teeth: the 45-deg cone only spanned
    4.5 of the 12.1 mm tooth depth. The ceiling that forced it is z_bot-
    relative, so DEEPENING THE BASE RAISES IT: tmin 10 -> 15 drops the flat
    bottom 5 mm and lifts the neighbour-plane ceiling 4.83 -> 9.83.
    gear_F = 9.5 now spans most of the tooth depth — a visibly 45-deg
    straight bevel ring (tips r305.8 at the wall -> r296.1 front), and the
    pinion is equally conical. Part lands at exactly 30.0 mm — the user-set
    thickness cap. Module unchanged (flush 5.384); C moves 325.5 -> 328.3.
    Two joint-face traps surfaced by the taller part, both fixed at de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
    [01_band.dxf, 02_slab.dxf, 02b_tail.dxf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]
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2026-07-26 Pololu #1596 motor: rectangular pocket, real specs, 5V/1RPM numbers
    Nick bought the motor: Pololu #1596 micro metal gearmotor, 1000:1 LP 6V
    — 13 rpm / 40 mA no-load, 5.5 kg-cm stall (~1000x the drive's need),
    10 x 12 mm RECTANGULAR body x26 incl. gearbox, 3 mm D-shaft x9.
    - bracket_stl: the round O12.5 pocket physically cannot hold a 10x12
    rectangle (15.6 mm diagonal) — replaced with a rectangular pocket
    (0.4 clearance/side, wide face parallel to the wall), boss sized from
    the body diagonal. 9/9 checks re-pass; viewer + STEP re-verified;
    plate 368.9 g / 9h30 PLA @15%.
    - Pinion bore unchanged: O3.2 + 0.4 flat fits the 3 mm D-shaft as-is.
    - Docs + CLAUDE.md: motor is BOUGHT, envel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
    [bracket_plate.stl, bracket_plate.stp]
2026-07-27 Rev B.5 crossed drive: shaft down, 10.8:1 for 1 RPM, rest-not-hang mounts
    Nick's architecture: "standoffs get higher, bottom bracket gets smarter,
    and top bracket only exists when we want to drive this bad boy."
    DRIVE — the 10T 45-deg pinion moves to a RADIAL axis at 12 o'clock
    (shaft straight down, Pololu #1596 above it in a shell). Ratio 108/10 =
    10.8:1 pairs the motor's 5 V no-load speed (13 x 5/6 = 10.83 rpm) to
    1.00 rpm at the ring — "pair it exactly with the rack count". Conjugacy
    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
    [05_bevel_cutter.dxf, bracket_bottom.stl, bracket_bottom.stp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]
2026-07-27 Right-size the crossed pinion (O100 -> O41) + the deferred cleanup pass
    Nick: "way out of scale… it should be right up on its nuts." Correct —
    the first crossed rev imposed the textbook rolling condition (pinion
    pitch = ring pitch / ratio -> rho 26.9, O100 big end, axis 36 off the
    wall, part 108 tall). The GENERATED drive never needed it: conjugacy
    comes from the CSG sweep under the imposed 10.8:1 motion, so only the
    tooth count (10) is forced. pin_rho and pin_face are now free params:
    - pin_rho 12, pin_face 10: tips O17 -> O41, axis 19.1 off the wall
    plane, dips just 1.2 behind it (wall_gap 18 -> 6). stand derives to
    31.0 -> part 61.0 mm tall (was 108), total wall depth ~67.
    - The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
    [05_bevel_cutter.dxf, bracket_bottom.stl, bracket_bottom.stp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]
2026-07-27 Drive view: wheels spun about each other's axles — pivot order fix
    wheel_l is built at 270+25 = 295 deg and wheel_r at 245 (bracket_stl
    wheels[] order: s_=+1 first), but the calculator's pivot list was
    [245, 295] — each wheel's spin pivot sat at the OTHER wheel's axle,
    ~270 mm away, so they orbited through space instead of spinning in
    place under the frame (Nick's catch). Pivot azimuths reordered to
    match; verified in-browser (ring animates, wheels static at their
    axles, no console errors).
2026-07-27 Top cluster: idlers under the motor as the pinion-preload datum + slots
    Nick: "Put the 2 idler wheels right underneath the motor… idling to
    preload the motor pinion which likely needs mounting slots."
    - DYNAMIC = ONE top unit. The two O48 idlers move back INSIDE the bore
    (ribs in the inner groove — internal engagement HANGS, external can
    only rest; both proven numerically this week) at ±12° from top,
    directly under the motor: they fix the ring's radial datum AT the
    meshing meridian, so tooth engagement cannot breathe. The bottom
    dynamic foot is gone.
    - The motor shell is now its own part (bracket_shell.stl) with two
    slotted ears (±8 mm vertical travel) clamping to the top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
    [bracket_bottom_static.stl, bracket_shell.stl, bracket_shell.stp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]
2026-07-28 GEARS.md: the bevel-gear clinic — why the generated pair works
    Nick's ask: explain why the gears work as-is, deep enough to be a
    clinic in algorithmically generating bevel gears. Eight sections, all
    code citations from the live scripts, every quoted number verified
    against Cfg/bevel_geom at head:
    1. The problem classical bevel theory can't solve (45-deg look +
    10.8:1 + shaft-down + wafers/drywall packaging — with the measured
    dead ends: 84.7/5.3 true-rolling cones, the apex 300 mm in front,
    the O100 rolling-sized pinion).
    2. The move: generation, not specification — conjugacy by construction
    via the CSG sweep (the volumetric analogue of hobbing), with the
    two lines that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
2026-07-28 Low-profile drive: 20T/5.4:1 pinion at the print floor, 22PG-2430BL motor
    Rev B.6 (Nick: "minimalist" beats exact-1-rpm; then "use this motor
    instead… 720:1 looks optimal"):
    - segment_stl.py: pin_T 10 -> 20 (108/20 = 5.4:1, ~2 rpm from an
    ~11 rpm shaft), pin_rho 12 -> 8 (0.8 mm section module — the FDM
    floor), pin_face 10 -> 7, gear_bl 0.6 -> 0.3 (0.6 would halve the
    0.8-module tooth), pinion bore 4.2 + 0.5 flat for the 22PG Ø4
    D-shaft. Derived stand 31.0 -> 17.6; part 61.0 -> 47.7 mm tall,
    total wall depth ~67 -> ~54. All gates green: mesh sweep 0.00000,
    clearance cut removes 0 of the teeth (ceiling 27.48), pair 0, genus 1.
    - bracket_stl.py: round-motor shell for the 22PG-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
    [05_bevel_cutter.dxf, 06_pinion.dxf, bracket_bottom_static.stl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]
2026-07-28 Tape jig: clamp drivetrain deleted, pegs become a drop funnel, zero hardware
    Nick 2026-07-27: "I'm no longer curing and am just taping it, simplify
    the jig knowing this new information." Tape grabs on first contact — no
    cure hold, so nothing needs to clamp; what tape DOES need is alignment
    BEFORE touchdown, since there is no repositioning.
    - cure_jig_stl.py (filename kept for CI/docs continuity): rod tension,
    captive hex nut, washer, printed knob, nut tower — all GONE. The two
    fences register over ONE printed Ø6.2 D-flat locating pin (331 mm,
    disc pull-head, prints lying on its flat, insert flat-down; an M6 rod
    still fits) through the existing keyhole. ZERO bought hardware. The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
    [cure_jig_fitcheck.stl, cure_jig_inboard.stl, cure_jig_knob.stl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]
2026-07-28 F625ZZ bearing idlers + every mount/jig hole on a 25 mm breadboard grid
    Nick 2026-07-27: "Make all of the jig and bracket holes spaced in 25mm
    increments so its easier for me to mock them up on a breadboard first"
    + "The idler wheels look way too unnecessarily big, find some suitable
    options online and size to them."
    Idlers: printed Ø48 wheels -> 2x BOUGHT F625ZZ flanged ball bearings
    (5x16x5, flange Ø18x1.0 — dims verified on RobotDigg/Amazon listings).
    The flange rides the existing inner groove as the rib (segment
    unchanged): ±0.25 float, +0.5 pull jam on the ledge; the 1.0 flange
    only meets the 45° chamfer roof after ~1.35 toward the wall, so each
    tower now carries a stop pad 0.5 b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
    [bracket_bottom_static.stl, bracket_shell.stl, bracket_shell.stp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]
2026-07-30 Streamlit straight-bevel critical-angle calculator (spherical involute)
    Implements the ZHY Gear article's step 1-6 pipeline (base cone, roll
    arcs, unfolding angles, measurement start angle theta_s) plus contact
    ratio, corrected against Ligata & Zhang 2011 (flank surface eq. 1,
    sin(db)=sin(d)cos(a)) and Litvin/Vullo/Radzevich. Three article errors
    demonstrated in --selftest and not reproduced: arctan base-cone form,
    domain-invalid arccos roll angle, and a contact-ratio formula that
    fails its own worked example by ~40x.
    Extras: Tredgold + exact-spherical contact ratios (agree to 0.002 on
    the reference example), undercut/apex-closure warnings, altair cone
    cross-section, loft-ready flank point-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
